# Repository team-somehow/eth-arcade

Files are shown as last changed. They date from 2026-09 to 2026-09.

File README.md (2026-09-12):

# ethonline-2026

TICK: a landscape **480×320** pygame crypto arcade for a Raspberry Pi handheld. **BOX RUN** is playable now: a box on the ETH price ladder and a 10-second clock that never stops — crank the dial to move the box, press A to buy the next 10 seconds. Prices are read-only. Money is paper by default; with `TICK_FUNDING=arc-testnet` it is real Arc testnet USDC: send it to the QR code on the device, play, and cash out back to the wallet it came from, through the [`TickEscrow`](contracts/) contract.

## Layout

| Path | What |
|---|---|
| [`firmware/`](firmware/) | Launcher + playable BOX RUN |
| [`design/`](design/) | Device renders, concept archive and actual game screenshots |
| [`substreams/`](substreams/) | The live ETH/USDC price: a Substreams module for Arbitrum and Base, the relay that serves it to the device, and `pools.py`, which finds pools in Messari's subgraphs |
| [`contracts/`](contracts/) | `TickEscrow`: USDC session escrow on Arc, with the owner as the house. Testnet: [`0x4FA3…8627`](https://testnet.arcscan.app/address/0x4FA3D366A08aD06D60A0aB141FFb9981EDeE8627) |
| [`ens/`](ens/) | Every player's wallet gets a `tick.eth` name on ENSv2 (Sepolia), with their stats as text records only the scorekeeper may write; the leaderboard is read back from ENS, on the device's LEADERS screen too |

## Where the prices come from

Every bet settles on the ETH/USDC price at the bell, so that price has to be live, updated every block, and hard to push. It comes from The Graph:

- **Substreams** (from The Graph Market) streams the swaps in every watched ETH/USDC pool on Arbitrum and Base, block by block: Uniswap v3 and v4 and Aerodrome Slipstream today, and any Sushiswap V3 pool `pools.py` adds. The module is built on Pinax's `uniswap_v3` and `uniswap_v4` packages, so it decodes no logs itself, and the same compiled module runs on both chains with only the pool list changed.
- **Messari's standardized subgraphs** say which pools to watch. They share one schema across protocols and chains, so `pools.py` asks Uniswap V3 and Sushiswap V3 the same question and gets back each pool's token order and decimals, which the module needs to turn a pool's state into dollars.
- **The device** combines the pools into one price, weighted by liquidity and leaving out any pool that strays from the rest, and prices the odds from how that price actually moves. More pools mean more trades, and more real moves to measure.

To play on it, run [`substreams/relay.py`](substreams/) and set `TICK_MARKET_SOURCE=substreams` in `firmware/.env`. The `sim` (default) and `coinbase` feeds are for playing without a relay.

## Quick start

```bash
cd firmware
python3 -m venv .venv
source .venv/bin/activate
pip install -r requirements.txt
python main.py
```

See [`firmware/README.md`](firmware/README.md) for controls and Pi/KMSDRM notes.

**On the device:** the dial moves your box up and down the price ladder; a short click buys the next 10 seconds (+10 USDC in paper play), pressing again adds more to the same box. Distance from spot sets the payout, priced from measured live volatility. On desktop, hold Up/Down to emulate a spun dial and press Escape to quit. See the [actual gameplay sheet](design/box-run-live/gameplay-sheet.png).

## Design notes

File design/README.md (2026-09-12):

# TICK design archive

## Current direction

White FDM case, charcoal painted bezel, existing red/yellow buttons, short side crank, tape assembly, Pi Zero 2 W, 3.5-inch landscape display. Enclosure size and crank attachment are NOT verified; measurements are required before CAD. Older screw-fastened and multi-color renders below are preserved as explorations, not the current build plan.

## Proposals in progress

- [INSERT COIN: the money and leaderboard flow](insert-coin/) — arcade-style deposit and payout, and a leaderboard that climbs your row one place at a time. 480x320 mockups, two animated moves, and the flow in plain words; not built yet. [Contact sheet](insert-coin/contact-sheet.png).

## Saved images and concepts

- [Latest crank / open-back appearance study](practical-crank/assembly.png)
- [Tape-assembled knob exploration](tick-tape-build.png) and [assembly notes](TAPE-BUILD.md)
- [BOX RUN six-step storyboard](box-run-storyboard/round.png) (archived concept)
- [BOX RUN hit/miss explanation](box-run-storyboard/outcomes.png) (archived concept)
- [Original device board](tick-device-concept.png)
- [Cream Cartridge exploration](render-round-2/01-cream-cartridge.png)
- [Graphite Terminal exploration](render-round-2/02-graphite-terminal.png)
- [Four game concepts](render-round-2/04-game-concepts.png)
- [Screen composition study](screen-studies.svg)
- [Initial long-form proposal](DEVICE-CONCEPT.md) and [two-day scope](TWO-DAY-PRODUCT.md)

All completed generated images available from the conversation are now copied into this repository. Some image generation requests were interrupted before returning an output (including the separate in-hand crank view and Orange Sandwich board); there are no completed files for those. Existing prompt files record prompts where available; the interrupted multi-image batches did not retain their prompt store. The render-round-2 README describes those proposed variants even when no image finished.

## Actual software screenshots

[BOX RUN gameplay contact sheet](box-run-live/gameplay-sheet.png) and individual screens in `box-run-live/` are rendered by the implemented pygame game, not imagegen. Recreate with `cd firmware && SDL_VIDEODRIVER=dummy SDL_AUDIODRIVER=dummy .venv/bin/python capture_box.py`.

The implemented game is BOX RUN: a box on the ETH price ladder with a 20-second window clock that never stops, priced from measured live volatility and staked in demo USDC. Two archives sit beside it — `box-run-build/` is the original aim/size/confirm version, whose sizing and confirmation steps were dropped, and `rush-build/` is a crank-a-flywheel detour (still runnable with `TICK_GAME=rush`). See [firmware instructions](../firmware/README.md) for running and controls.

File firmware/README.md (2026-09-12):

# ETH ARCADE / BOX RUN

Native pygame game for a **480×320 landscape** handheld. Runs on desktop for development and on the Pi's configured SDL display.

**BOX RUN** is a box on the ETH price ladder and a clock that never stops. A 10-second window is always running; **cranking the dial moves your box** up and down, and **A buys the next 10 seconds** at wherever the box is sitting. At the bell, the window settles against the live price — inside the box and you're paid, outside and the stake is gone — and the next window starts in the same frame. There is no size step, no confirmation, and no early exit.

The box is **always the same size** — $1.41 on $2,500 ETH — so there is nothing to learn about it and nothing that changes under you. How far you park it from spot is the only decision, and only the *payout* reacts to the market.

## Controls

The rotary encoder is the game: GPIO21 CLK, GPIO20 DT, GPIO16 switch, 3.3 V logic. Two panel buttons sit beside it, each shorting its pin to ground against the internal pull-up — nothing else in hardware:

| Button | BCM | Header pin | Does |
|---|---|---|---|
| Red | GPIO13 | 33 | Back / home (same as a long encoder click) |
| Yellow | GPIO26 | 37 | Buy / confirm (same as an encoder click) |

Ground for both is any GND pin; 34 and 39 are the nearest. **BCM numbering, not header position** — GPIO13 is pin 33, GPIO26 is pin 37, which is where this usually goes wrong. Presses are edge-triggered, so holding a button repeats nothing, and a button held while the game starts is ignored rather than firing on the first frame. If the pins are missing or already claimed, the pad simply does not open and the encoder carries on alone.

| Input | Action |
|---|---|
| Turn the dial | Move the box up/down the price ladder — until a bet is placed |
| Short click | Buy the next 10 seconds: +10 USDC on the box where the cursor is |
| Long click (0.65 s) | Back to the launcher |

Press A again in the same window and the extra 10 goes onto **the same box** — the first press fixes that window's level. After that the dial is **locked out entirely**: the box does not move, does not shrink, and no second cursor appears. Only money can still be added, and only by pressing A. The dial frees up again when the bell rolls the window over.

Placing a bet turns the dashed box **solid where it stands**, with a pop. That is the signal that the dial is no longer yours: turn it anyway and the box shakes and the status line says `LOCKED / YELLOW ADDS 10`.

Spending money on a dial nudge would be worse than a dead dial, which is why adding stake stays on the button.

Desktop and touch equivalents: Up/Down (or W/S) held down emulates a spun dial, Right/Enter/Space is the short click, Left/Z/Backspace the long one, `F` opens the loader, and **Escape quits the program immediately** from any screen. On a desktop the game opens in a plain 480×320 window; only the Pi gets the fullscreen panel. Tapping above the aim box raises it and tapping below lowers it (`design/box-run-live/touch-zones.png`); buying stays on the button.

`TICK_GAME=rush` still selects the earlier crank-a-flywheel game; `box` is the default.

The launcher is an attract screen in the same night city: the rider runs a scripted demo loop — a hit, a backflip, a hat trick, then a greedy miss that puts the fire out — under a bobbing logo, with the live ETH price in the corner. The demo line is made up; the ticker and the balance are real. PLAY and LOAD USDC sit on the street; the dial toggles between them, and tapping anywhere in the scene plays.

## Reading the screen

Time is one horizontal scale across the whole screen, 16 px a second. A rider on a one-wheeler sits a quarter of the way in at *now*, the wheel resting on the live price; history trails off to the left, and every bell is a dotted post ahead that slides toward the wheel. A box is drawn centred on the post of the bell it settles at, so it arrives under the wheel at the exact moment it is judged: be inside it as you pass through and you're paid. There are no columns.

| On screen | Meaning |
|---|---|
| `+0.62` beside the price | How far the price has come since this window opened |
| Dashed grey line, `OPEN` | The price this window opened at — the chart is anchored here |
| `07s` over a post | Time to this window's bell |
| Dotted line ahead of the wheel | Where the price is now, carried forward to read against the boxes |
| Solid yellow box | Your live bet, arriving at this bell; it glows while the price is inside |
| Solid cream box | Bought and locked for the next bell |
| Dashed yellow box | The cursor, with its live quote; a fresh one slides in from the right after every bell |
| Green / red box behind the rider | A box that already settled, with a dot where the price landed |
| `20 @ 2.0x` | Stake on that box and the multiple it pays |
| Small triangle | The box sits past the top or bottom of the visible band |

The wheel is a single wheel on purpose: the price line is jagged, and legs or a two-wheeled base would visibly clip into it, while one wheel touches it at exactly one point. The rider leans into the slope and reacts to results — a hop on a hit, a backflip on 5x or better, a wobble on a miss. **Three hits in a row is a hat trick**: the rider leans back into a one-wheel wheelie with a jetpack on fire, and stays lit until a miss puts it out.

The scene — sky, two parallax rows of city, the street, the rider — is drawn in code (`games/box_scene.py`), like the sound, with no image assets. Everything moves on the clock rather than on ticks, and the wheel, the camera and the cursor ease toward where the model says they are, so a price tick or a detent is a glide rather than a jump.

The visible band is exactly **two box-heights either way** (±$2.83 on $2,500 ETH), which is what makes a dollar of drift a visible swing rather than a wobble. Widening it to fit every reachable box would flatten the price back out, so a box cranked to the far edge is clamped with a triangle instead.

**The chart is anchored on the window's opening price, not on spot.** Anchoring on spot re-centres the view every tick and pins the newest point to the middle of the screen, which makes movement impossible to see — the price appears still while the world slides around it. Against a reference that holds still for the whole window, a move reads immediately, and the `MOVE` figure puts a number on it.

## Odds

Distance is the whole risk decision, so the payout is priced from what the market is actually doing rather than a fixed table. Park the box on spot for roughly 2x; crank it to the edge of its reach for 10x or more, capped at 25x.

Geometry is fixed in basis points of the window's opening price — a $1.41 box, 18c crank steps and $2.12 of reach on $2,500 ETH — so **volatility moves the odds and never the box**.

Those numbers are quoted for a 20-second window and **scaled by the square root of time**, because that is how far a price travels. `WINDOW_S` is therefore a safe knob: halving it without shrinking the box would leave a box on spot a near-certainty paying 1.2x and everything else pinned to the cap — a flatter game, not a faster one. Scaled, ten-second windows keep the ladder the twenty-second build had: about 1.5x on spot at the bell, 25x at full reach, 2.0x to 9.7x for the same boxes bought a window early. Sizing the box in sigma instead (as this first did) means a bet already placed gets redrawn at a different size when the market picks up, which is both confusing and dishonest about what you bought. The cost of fixing it is that a violent market makes the same box genuinely hard to hit; the multiple rises to match, which is the honest response rather than quietly making the target bigger.

The estimator is **realized variance over the last minute of wall time**: squared returns summed and divided by the time they span, with time spent sitting on one price counted as exactly that. A pool nobody swaps in, or a ticker with no new trade, is a calm market — and the bell settles on that same price, so pricing it as a typical one sells a near-certain box at 2x. The first version skipped repeated prices and fell back to "typical ETH" whenever it saw too few moves, which is precisely what a flat Coinbase or Substreams stretch produces: parking the box on the line won 58 bets out of 58. A flash spike or feed glitch is kept from inflating the odds by capping each move at four times the median move. And every estimate is made as if the window began with ten seconds of ordinary ETH, so the first seconds of data, or a market just waking from a lull, are not priced as if nothing could move; a minute of real data outweighs that six to one. The estimate is cached per tick, so the renderer can ask for it freely.

**A quiet market sells nothing.** If the price has not changed for 15 seconds, A refuses with `MARKET QUIET / NO BETS` and the aim box reads `QUIET`: on a line that never moves, a box on spot is a certain win at any multiple over 1x. Nothing that quotes under 1.05x is sold either: a near-certain box is not a bet worth selling. At start-up nothing is sold until the feed has been read — it has moved, with three seconds or ten moves behind it, since a feed that has not moved yet cannot be told from a dead one — and the screen says `READING THE MARKET...`; prices are read from boot, behind the launcher, so this is normally over before you press play. Bets already down ride to their bell as normal.

Two details that matter for fairness. Each press is priced at **that press's** odds, so topping up a box after the price walks toward it costs what it's worth then, not what it was worth when the level was fixed. And the horizon runs to the bell being bought, so buying 15 seconds early prices 35 seconds of drift — a different bet, not a free one.

## Sound

Everything is synthesized at startup — square waves, no audio assets, no dependencies — and it builds in about 0.16s.

### Music

Three looping beds, and the game picks one every frame from what is actually at stake:

| Bed | When | What it is |
|---|---|---|
| `idle` | Launcher, or nothing staked | Sparse A-minor bass and a slow arpeggio |
| `live` | Money on the next or current window | Driving bass, fast arpeggio, offbeat hats |
| `final` | Last three seconds of a live bet | Same bass, a tense descending lead, hats on every step |

Each bed is layers of **monophonic** 2-second loops, one per reserved mixer channel, so the mixer does the polyphony and Python never mixes a sample — which matters, because `audioop` was removed in 3.13. Loops are assembled from a cached palette of note renders rather than computed per sample per bar, which is the difference between 0.16s and several seconds of work at boot on a Pi. Every layer in every mode is exactly the same length, so switching bed restarts the bar cleanly instead of drifting the parts apart.

### Cues

A clip is a list of (start_hz, end_hz, seconds) segments, with phase carried across segments so a clip can glide in pitch instead of only beeping. Every cue answers a question you would otherwise have to read off the screen:

| Cue | When |
|---|---|
| Rising detent clicks | Every crank step, pitched by how far out the box has moved — the risky end of the reach sounds higher |
| `buy1` → `buy2` → `buy3` | Stacked presses on the same box, each a note higher |
| Upward swoop | The price just crossed **into** your live box |
| Downward swoop | It just crossed **out** |
| Ticks in the last 3s | Pitched high if the money is currently winning, low if it is not, and doubling in rate inside the final two seconds |
| Two-tone bell | A window rolled with no money down — the game's heartbeat. A result speaks instead of the bell |
| Fanfare | A win, longer and higher above 5x |
| Falling thud | A miss, or a flat neutral one for a voided window |
| Longer, higher fanfare | A jackpot at 15x or more |
| Tiny high click | The box passing over spot as you crank through it |
| Double low buzz | Cranking a box that is already locked |
| Falling sweep | The price feed went stale |
| Blip / rising chime / falling chime | Menu move, entering the game, backing out |
| Two-note chime | USDC loaded |

The two that matter most are the box-crossing swoops and the pitched countdown: together they tell you whether you are winning without looking, which is the whole point of a handheld you play with your thumb.

Levels are sized so three overlapping cues plus a bed peak at about 21k of 32767 — nothing clips, and the music sits at roughly half the level of the cues.

**Audio output on the Pi.** A Pi 5 has no analog jack, so ALSA alone offers only the two HDMI outputs and opening one fails with nothing connected. Sound works through the **pipewire-pulse** server instead — on this device that reaches a paired Bluetooth speaker. Do not force `SDL_AUDIODRIVER=alsa`: it bypasses the sound server and finds only the dead HDMI sinks. If the mixer cannot open at all, the game runs silently by design (`Sounds` catches it and every `play` and `music` becomes a no-op, which is tested).

Bluetooth adds 100-200ms of latency, so crank clicks trail the dial. A USB audio dongle is tighter; an I2S DAC such as a MAX98357A is tightest, but **it wants GPIO18/19/21 and GPIO21 is currently the encoder's CLK pin**, so the encoder would have to move first.

## Settlement

Only the price **at the bell** counts; sailing through the box mid-window pays nothing, and the boundary counts as inside. A quote from before the bell cannot settle a window however fresh it looks, so the display holds on `SETTLING` until a price stamped after the bell arrives. If none arrives within 4 seconds, the window is **voided and the stake refunded** — settling a real bet against the wrong moment's price is worse than not settling it. A stale feed also blocks new bets.

## Money

Balances are integer **micro-USDC** (6 decimals, the real USDC unit) so a session cannot accumulate float drift; payouts truncate downward rather than rounding money into existence. `wallet.py` holds the funding seam:

| `TICK_FUNDING` | Backend | Behavior |
|---|---|---|
| `demo` (default) | `DemoFunding` | Starts at 100 and mints local play money on +10/+25/+100 |
| `arc-testnet` | `arc.ArcFunding` | Real Arc testnet USDC through the [`TickEscrow`](../contracts/) contract. BOX RUN only |

`TICK_STAKE_USDC` sets the stake per press of A in BOX RUN and per ride in RUSH: 10 by default, as little as 0.000001. It is parsed as an exact decimal, and labels and balances show as many decimals as the stake has, so a 0.001 stake reads `0.001`, never `0.00`.

**Real USDC.** With `TICK_FUNDING=arc-testnet` the money button on the launcher reads INSERT COIN and opens `screens/money.py`, which shows the device's own Arc address as a QR code. Scan it in MetaMask and send any amount of USDC on Arc testnet. The device watches Arc for transfers to itself, keeps 0.01 of each for gas (USDC is Arc's gas token; set it with `TICK_GAS_FEE_USDC`), and locks the rest in `TickEscrow` with `openFor`, in the sender's name. That takes about 8 seconds. The launcher then shows `+0.49 USDC FROM 0x7ee8..CCac` and its money button turns into CASH OUT.

Bets run on the device exactly as in demo play. CASH OUT refunds a box bought for the next window, lets the live one land, then closes the session with the final balance, and the escrow pays it straight back to the address the USDC came from. The escrow pays out at most 5x a deposit, so a press that could win past that is refused with `MAX WIN REACHED / CASH OUT`. A deposit the house cannot cover, or one over the 2.5 USDC maximum, is sent back.

**The money screen** is one screen with four faces, and only one of them is up at a time — designed in [`design/insert-coin`](../design/insert-coin/). Which face is drawn comes from funding state that already exists on `ArcFunding`, plus two timers:

| face | when | ● B | ◆ A |
|---|---|---|---|
| INSERT COIN | no session open | home | — |
| COIN DROP | a deposit just landed | home | **PLAY NOW**, straight into the game |
| CASH OUT? | money down, money button pressed | not yet | **YES**, after a 0.5s beat |
| CASHING OUT | the payout is in flight | — | — |
| the ticket | the payout landed | home | see your rank |

The coin drop falls back to the launcher with PLAY focused if nobody presses anything for three seconds, and the ticket hands itself to the leaderboard after 2.5. CASHING OUT has no buttons, because pressing one cannot make Arc faster — but if the payout is still going after eight seconds (`PAYING_HOLD_S`) the red button becomes `< LEAVE IT RUNNING`, since the worker finishes the transaction whatever is on the panel and the launcher says so when it lands. The cash-out question exists because that press is the only irreversible, screen-less action on the device: the A that opens the card is ignored, so it takes a second, deliberate press to send the money. The ticket reports the run — in, out, P&L, boxes, hits, best win and the tx — from a `Ticket` snapshotted in `BoxGame.sync_funding` the moment the cash-out lands, because everything on it is about to be reset. Paper money keeps its own `+10 / +25 / +100` chooser inside `BoxGame`; none of this applies to it.

**The leaderboard moves.** `screens/board.py` reads every `tick.eth` player from ENS, best P&L first, and the wallet on this device is picked out — in the list, or pinned under it with its real rank. Arriving from a payout it does something more: `BoardScreen.arrive()` is handed who just cashed out and what their run was worth, and from then until the scorekeeper catches up the board **holds the picture it already had**, ghosts the pending P&L beside your old row, and says `SCORING YOUR RUN ON ENS`. `BoardFeed` parks a good read in `pending` instead of swapping it in, and polls every 3s rather than 20 while it is waiting — the scorekeeper writes a few seconds after the escrow closes, so this is usually one or two reads. A run counts as scored when the name's `tick.sessions` goes up, the only signal ENS gives us.

Then the board is *seen* to change rather than found already changed. `Move` is the whole animation: 0.7s holding, one adjacent swap every 0.52s, 1.7s to settle. Your plate lifts over the list, the row above slides under it, both numbers roll at the same instant so they never read as the same rank, `UP 1` becomes `UP 2` becomes `UP 3`, and your P&L counts up the whole way — to cents while it runs, exact when it rests. Land in the top three and confetti comes off the plate under `ON THE PODIUM!`; a bad run runs the same movement downward with no celebration at all, just `THAT ONE COST YOU. GO AGAIN?`. Two cases have no row to trade places with, so the number itself counts instead: a player pinned below the visible six, and a first ever run, whose row drops in from the top and stamps `NEW ENTRY`. If ENS has not been written after 45 seconds (`SCORE_WAIT_S`) the board says so and goes back to being a board. Afterwards the yellow button reads `PLAY AGAIN` and goes to INSERT COIN, which closes the loop.

The device key is created on first run in `firmware/.tick/device.json`, and the open sessions, balance and last block read are saved in `.tick/arc-testnet.json`; the folder is gitignored. A restart resumes play and finishes an interrupted cash-out. Chain work runs on its own thread, so a slow RPC never stalls a frame. Real funds need `eth-account` and `qrcode` from `requirements.txt`; demo play does not. The odds still carry no house edge.

## Prices

| `TICK_MARKET_SOURCE` | Feed |
|---|---|
| `sim` (default) | Seeded 20 Hz Gaussian walk at roughly live ETH volatility — about 0.03% over ten seconds. Tick spacing is counted in integer microseconds, so the same wall-clock time produces the same ticks at any frame rate |
| `coinbase` | Public Coinbase REST ticker at 5 Hz on a worker thread, read-only |
| `substreams` | ETH/stable pools on Arbitrum and Base (Uniswap v3 and v4, Aerodrome Slipstream), from The Graph's Substreams via `substreams/relay.py` on a laptop or server at `SUBSTREAMS_BASE_URL`. One tick per block, priced as the liquidity-weighted average of the pools, leaving out any pool more than 0.5% from the rest, and aged by block time |

`TICK_ASSET` picks the coin: `eth` (default), `btc`, `sol` or `hbar`, each priced in USD, and HBAR shown to five decimals. `sim` starts each coin at a typical price and walks it at that coin's rough live volatility, and `coinbase` polls its `-USD` product. `substreams` watches ETH pools only, so it refuses any other coin. Box geometry is in basis points of price, so the game plays the same on any of them.

The Substreams feed repeats the last price on blocks where nothing traded, because that is still each pool's price. Volatility therefore counts only moves, measured from the previous move, or those repeats would read as a calm market.

Settings like this one live in `firmware/.env` (copy `.env.example`), which `main.py` reads at startup. A value set in the shell overrides the file, so `TICK_MARKET_SOURCE=coinbase .venv/bin/python main.py` works for a one-off run.

A 20-second window needs a trace rather than a staircase, which is why the live adapter polls at 5 Hz (well inside the public rate limit) instead of once a second. Payloads are validated before use — finite positive price, timezone-aware timestamp, no future stamp — and carry a sequence number and source age, so out-of-order or stale ticks cannot price or settle anything. A production adapter should use the venue's WebSocket trade stream.

The feed is read-only. With demo money every bet is paper; with `arc-testnet` the bets still run on the device, and only deposits and cash-outs touch the chain.

## Run, test, capture

```sh
cd firmware
.venv/bin/python main.py                    # or: python3 -m venv .venv && .venv/bin/pip install -r requirements.txt
SDL_VIDEODRIVER=dummy SDL_AUDIODRIVER=dummy .venv/bin/python -m unittest discover -s tests -v
SDL_VIDEODRIVER=dummy SDL_AUDIODRIVER=dummy .venv/bin/python capture_box.py
```

On Raspberry Pi, install the distribution's `python3-pygame` and run `python3 main.py` with the panel configured; the display bootstrap may re-exec under system Python for KMSDRM support.

Captures go to `design/box-run-live/` at native 480×320, rendered by the real game rather than image generation. Tests cover the window clock rolling on its own, buying and topping up, the cursor never moving a bought box, box height tracking measured volatility, fair odds against the stated probability, the multiple cap, inside/boundary/outside settlement, pre-bell quotes being rejected, voiding after a feed gap, whole-micro payouts, and every screen rendering.

## Pi display note

`hardware.md` records a prior Pi 5 setup, including KMSDRM device index **2**. The actual Pi Zero 2 W may use another index. Set `SDL_VIDEO_KMSDRM_DEVICE_INDEX` for the connected panel when running without a desktop; do not assume the Pi 5 card index applies. Display overlays, refresh rate, encoder direction and physical fit still need on-device verification, as does whether the SPI panel sustains the target 30 FPS full-frame redraw.

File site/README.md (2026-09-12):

# ETHarcade.fun landing page

Run `npm install` and `npm run dev`. Build the deployable site with `npm run build`.

## SDK documentation on the same origin

The complete SDK docs site is served at `/docs/`, including its sidebar,
search index, examples, source pages, theme switch, and mobile navigation.
The landing page's Docs link and SDK resources point there.

`predev` and `prebuild` copy the committed `../sdk/web/dist/` site into
`public/docs/`, so the production output includes `dist/docs/`. Deploy the
entire `site/dist/` directory. Serve existing static files before any SPA
fallback so `/docs/*.html`, scripts, and styles remain accessible.

After changing SDK Markdown or Python source, run `npm run docs:generate`
(Python 3 required) and commit the regenerated `sdk/web/dist/` files. Normal
landing-page builds only need Node, using that committed documentation build.
The copied `public/docs/` directory is generated and ignored by Git.

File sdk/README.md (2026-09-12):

# TICK SDK

Build a crypto arcade game for the TICK handheld in one file.

The device is a 480×320 landscape screen, a rotary dial, two buttons and a
speaker. A game on it is always the same shape: **a claim about where a price
will be at a known moment, backed by money**. This SDK owns everything around
that claim — the live price, the clock, the odds, the wallet, the settlement,
the input and the noise — so your game only has to say what a bet *is*, what
wins, and what it looks like.

```python
from tick import Game, run
from tick.hud import clear, draw_clock, draw_hud
from tick.ui import YELLOW, say

class Coinflip(Game):
    title = 'COINFLIP'
    window_s = 10.0

    def setup(self, ctx):
        self.pick = 'UP'

    def on_action(self, ctx, action):
        if action.name in ('UP', 'DOWN'):
            self.pick = action.name
        elif action.name == 'A':
            anchor = ctx.open_price
            ctx.bet(anchor, 1e9) if self.pick == 'UP' else ctx.bet(0.0, anchor)

    def draw(self, ctx, screen):
        clear(screen)
        say(screen, self.pick, 240, 120, 32, YELLOW, center=True)
        draw_clock(ctx, screen)
        draw_hud(ctx, screen)

run(Coinflip())
```

That is a complete, playable game with live prices, fair odds computed from
measured volatility, a round clock that never stops, an integer-USDC wallet,
dial and button input, and a full set of arcade sound cues.

## Install

```bash
cd sdk
python3 -m venv .venv && source .venv/bin/activate
pip install -e .                 # demo play: only pygame
pip install -e ".[chain]"        # + real USDC settlement and ENS names
pip install -e ".[pi]"           # + the dial and the panel buttons
tick doctor                      # what is installed, and whether the feed answers
```

Python 3.11 or newer.

## Sixty seconds

```bash
tick new mygame          # scaffold a playable game
python mygame.py         # play it on simulated prices
tick prices --source coinbase --limit 10       # watch a live feed in the terminal
tick run mygame.py --source coinbase           # play it on real prices
```

## What you get

| Layer | Module | What it owns |
|---|---|---|
| Ticks | `tick.feeds` | one validated `PriceTick`; simulated, exchange, on-chain and recorded feeds |
| Market | `tick.market` | history, realized volatility, fresh / quiet / ready, probability of a range |
| Odds | `tick.pricing` | chance → fair multiple, with a cap, a floor and a house edge you set |
| Money | `tick.money` | integer micro-USDC wallet; nothing here is a float |
| Settlement | `tick.escrow` | deposits, sessions and payouts on-chain, on a worker thread |
| Identity | `tick.identity` | a readable name per wallet, and a leaderboard read from ENS |
| Rounds | `tick.rounds` | the clock that never stops, and refuses to settle on the wrong price |
| Bets | `tick.bets` | place, top up, settle, refund — the only code that moves money |
| Your game | `tick.game` | `Game` and `GameContext` |
| Loop | `tick.runtime` | `run()`: 30 FPS, input, cues, shutdown |
| Screen | `tick.hud`, `tick.ui` | price ladder, HUD, palette, synthesized sound |

## Documentation

All of it is also a **browsable site** with search, built from these same
Markdown files — open [`web/dist/index.html`](web/dist/index.html) straight
from disk, or:

```bash
tick docs                # build it and open a browser
python web/build.py      # build only, into web/dist/
```

* **[PLAN.md](PLAN.md)** — the system from first principles, with examples, and
  the increment-by-increment plan to build or extend it.
* [docs/writing-a-game.md](docs/writing-a-game.md) — the tutorial, start here.
* [docs/prices-substreams.md](docs/prices-substreams.md) — putting an on-chain
  price under your game: Substreams, the relay, and how many pools become one
  number you can settle on.
* [docs/money-arc.md](docs/money-arc.md) — real USDC: the escrow session model,
  why there is no transaction per bet, and how a player cashes out.
* [docs/identity-ens.md](docs/identity-ens.md) — giving every wallet a name and
  a public record with ENS, and reading a leaderboard back out of it.
* [docs/device.md](docs/device.md) — the screen, the dial, the buttons, the Pi.
* [docs/api.md](docs/api.md) — the whole public surface on one page.
* [web/README.md](web/README.md) — how the docs site is generated, and how to
  add a page to it.

## The command line

```
tick doctor                          what is installed, configured and reachable
tick new mygame                      scaffold a game
tick run mygame.py [--source ...]    play it
tick prices [--source coinbase]      print the feed
tick pools [-v]                      print every pool in the on-chain stream
tick record -o eth.ndjson --seconds 300      save a real market
tick replay eth.ndjson --speed 10            play it back
tick board                           the leaderboard, read from ENS
tick docs [--port 8000]              build the documentation site and open it
```

## Testing a game

Games that hold money need tests, and a game loop is testable only if it can
run without a window. `tick.testing.Harness` runs your real game class against
a real market on a clock you control:

```python
from tick.testing import Harness
from mygame import MyGame

def test_a_wide_bet_is_never_sold():
    h = Harness(MyGame(), seed=7).warm(25)
    assert h.ctx.bet(h.price * 0.5, h.price * 1.5) is None
    assert h.ctx.refused == 'TOO SURE TO SELL'
```

```bash
SDL_VIDEODRIVER=dummy SDL_AUDIODRIVER=dummy python -m unittest discover -s tests -t .
```

## Settings

Everything is configured by environment, read from a `.env` beside your game
(copy `.env.example`). Anything set in the shell wins, so a one-off run is
`TICK_MARKET_SOURCE=coinbase python mygame.py`.

| Setting | Values |
|---|---|
| `TICK_MARKET_SOURCE` | `sim` · `coinbase` · `substreams` · `replay` · `frozen` |
| `TICK_ASSET` | `eth` · `btc` · `sol` · `hbar` |
| `TICK_FUNDING` | `demo` · `arc-testnet` |
| `TICK_STAKE_USDC` | money per bet, e.g. `10` or `0.001` |
| `TICK_WINDOW_S` | round length, if the game does not fix it |
| `TICK_ROTATE` | `auto` · `0` · `90` · `180` · `270` |
| `TICK_SOUND` | `1` · `0` |

## Examples

| File | What it shows |
|---|---|
| [`examples/coinflip.py`](examples/coinflip.py) | the smallest real game: up or down at the bell |
| [`examples/ladder.py`](examples/ladder.py) | park a box on the price — the shape most games take |
| [`examples/ticker.py`](examples/ticker.py) | the data layer with no game and no pygame |
| [`examples/pools.py`](examples/pools.py) | every pool in the on-chain stream, block by block |

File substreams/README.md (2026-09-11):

# tick_eth_price

A Substreams module that reads Uniswap v3 and v4 swaps and outputs a per-block price for a chosen set of pools, on any EVM chain. Aerodrome's Slipstream pools emit the same swap event as Uniswap v3, so they work too. It is the ETH price source for BOX RUN, where each bet settles on the ETH price at the end of a ten-second window.

## Why several pools on two chains

A bet settles on one number, so that number has to move often, be hard to push, and reflect the market rather than one venue. One pool does none of that well.

- **It updates often.** Any one pool can go several seconds without a trade. Over one minute with all twelve pools, the combined price changed 41 times and never stood still for more than 2 seconds, one Base block.
- **It is hard to push.** A price taken from one pool can be moved by one large trade at the bell. Moving the median of many pools on two chains at the same moment costs far more.
- **It is a fairer price.** Pools disagree. At one moment on Base they were $3.47 apart, more than twice the height of a box in the game.
- **It gives the odds real moves to measure.** BOX RUN prices every box from the volatility it measures in the last minute of prices. A stretch where no watched pool trades reads as a calm market, and after 15 seconds of it the game stops selling. Every pool added is one more venue whose trades move the price.

The price is only a reference; bets never trade in these pools. They can settle in USDC on any chain, and the price is read where ETH has the deepest liquidity.

## How it works

```
sf.ethereum.type.v2.Block ──▶ Pinax uniswap_v3:map_events ──┐
sf.ethereum.type.v2.Block ──▶ Pinax uniswap_v4:map_events ──┤
sf.substreams.v1.Clock ─────────────────────────────────────┼──▶ map_pool_prices ──▶ tick.v1.BlockPrices
sf.ethereum.type.v2.Block ──────────────────────────────────┘
```

- **It builds on Pinax's `uniswap_v3` and `uniswap_v4` packages** instead of decoding logs itself. Those packages already turn every Uniswap log into typed events; this module keeps only the swaps for the pools it was given and converts each pool's `sqrtPriceX96` into a decimal-adjusted price. A v3 or Slipstream pool is named by its address. v4 keeps all its pools inside one contract, so a v4 pool is named by its 32-byte pool id.
- **It keeps no state between blocks**, so it starts at the chain head straight away, with nothing to backfill.
- **It emits a message for every block**, including blocks where nothing traded, so a consumer can tell a quiet market from a dead stream. The raw block is an input for this reason only: the engine skips a module whose inputs are all empty, and many Arbitrum blocks carry no Uniswap v3 event.
- **Every message carries its block time**, so a price is placed against the bell rather than against when it arrived. In testing, messages arrived about a second after each block.
- **The same compiled module runs on Arbitrum and Base.** Only the pool list changes.

The module reports each pool's price and in-range liquidity. Combining them is left to the consumer. BOX RUN averages them weighted by liquidity, after leaving out any pool more than 0.5% from the rest, so a trade in any pool moves the price by that pool's share.

## Where the pool list comes from

Every pool needs its token order and decimals, or its `sqrtPriceX96` turns into the wrong number. Messari's standardized DEX subgraphs on The Graph hold both for every pool, in one schema that is the same for every protocol and every chain. `pools.py` relies on that: it sends one query, unchanged, to every subgraph listed in `.env`, and adds the ETH/USDC pools it finds to the pool list.

```graphql
{
  protocols(first: 1) { name network }
  p0: liquidityPools(first: 20, where: { inputTokens: ["<WETH>", "<USDC>"] }) {
    id
    name
    inputTokens { id symbol decimals }
    inputTokenBalances
    fees { feeType feePercentage }
  }
}
```

The subgraphs are Uniswap V3 on Arbitrum and Base, and Sushiswap V3 on Arbitrum. Sushiswap V3 pools emit the same swap event as Uniswap v3, so Pinax's `uniswap_v3` package decodes them and this module prices them with no change. A new protocol costs one subgraph id in `.env`, and nothing else.

```sh
python3 pools.py             # add what it finds to .env
python3 pools.py --dry-run   # show it and change nothing
```

It keeps pools with a trading fee of 0.05% or less that hold at least 25,000 USDC. Pools with higher fees are left out: nobody corrects their price until it is a fee off, about $7 at 0.3%, which is more than a box. Size is read from the USDC the pool holds rather than from the subgraphs' USD figures, which put some of the biggest pools at $0.

It only ever adds. A pool already listed stays exactly as written, and a chain whose subgraphs cannot be reached keeps its list, so a bad run never costs the ETH/USDC price a pool. Restart `relay.py` afterwards to stream the new pools. It needs `GRAPH_API_KEY` in `.env`, an API key from [Subgraph Studio](https://thegraph.com/studio).

The Slipstream and v4 pools have no Messari subgraph, so they are listed by hand: picked by trading volume, with their token order and decimals read from the pool contracts.

Each output price includes the hash of the transaction behind it, so a settled window can be checked afterwards against the swap the subgraph recorded for that pool.

## Output

One `BlockPrices` per block, listing only the pools that traded in it:

```json
{
  "blockNumber": "503790132",
  "timestampMs": "1789063794000",
  "prices": [{
    "pool": "0xc31e54c7a869b9fcbecc14363cf510d1c41fa443",
    "price": 2456.759457684401,
    "sqrtPriceX96": "3927000007035700886487060",
    "liquidity": "26649090794393043",
    "swaps": 1,
    "ordinal": "5773",
    "txHash": "0x39ed645a77cad585294f380650d60576137a6892c0598dcecfd5b0fcda04bc3c"
  }]
}
```

## Run

Get a key from [The Graph Market](https://thegraph.market) with `substreams auth`, or set `SUBSTREAMS_API_KEY`. Then:

```sh
cargo build --target wasm32-unknown-unknown --release

# Arbitrum, with the default pool list
substreams run ./substreams.yaml map_pool_prices -e arb-one.streamingfast.io:443 -s -1 -o jsonl

# Base: same module, different pools
substreams run ./substreams.yaml map_pool_prices -e base-mainnet.streamingfast.io:443 -s -1 -o jsonl \
  -p map_pool_prices=0xd0b53d9277642d899df5c87a3966a349a798f224:18:6
```

Pools are passed as `0xpool:decimals0:decimals1`, comma-separated, where `0xpool` is a pool address or a v4 pool id. Add `:invert` to quote token0 per token1 instead of token1 per token0.

## Choosing chains

`stream.sh` reads `.env` (copy it from `.env.example`) and starts one stream for each chain in `TICK_CHAINS`. It merges them into a single JSON-lines stream and adds a `chain` field to every line.

```sh
TICK_CHAINS=base            # one chain
TICK_CHAINS=arbitrum,base   # both
```

To add a chain, set its endpoint and pools as `TICK_ENDPOINT_<CHAIN>` and `TICK_POOLS_<CHAIN>`. For `pools.py` to find its pools too, add its subgraphs, WETH and USDC as `TICK_SUBGRAPHS_<CHAIN>`, `TICK_ETH_<CHAIN>` and `TICK_USDC_<CHAIN>`.

## Serving it to the device

The handheld does not run Substreams itself. `relay.py` runs `stream.sh` on a laptop or server and serves the same lines over HTTP. It needs the built module, `.env` and a Substreams key, as above.

```sh
cd substreams
python3 relay.py                  # serves http://<this machine>:8787/stream
python3 relay.py --port 9000      # another port

# check it from another terminal: one JSON line per block
curl -N http://localhost:8787/stream
```

Stop it with Ctrl+C; that stops the streams too.

The device keeps one connection open to `/stream` and gets each block as soon as it arrives, so the relay adds only the local network's delay. A device that connects is first sent the latest price of every pool that has traded since the relay started, so it does not have to wait for each pool's next trade. The Substreams key stays on the relay's machine.

On the device, set `TICK_MARKET_SOURCE=substreams` and `SUBSTREAMS_BASE_URL=http://<relay address>:8787` in `firmware/.env`.

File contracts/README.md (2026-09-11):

# contracts — TickEscrow on Arc

`TickEscrow` is a USDC escrow for TICK play sessions, with the owner as the house. Bets run off-chain on the device; the chain holds both sides' money and settles each session in one transaction.

- **The house** is the owner's USDC, funded with `fund` (a small bankroll, $10–20 on mainnet). A player's loss stays with the house; a win is paid from it.
- **A session** is one player's USDC locked for one device. When play ends, the player is paid the device's final balance.
- **A device can open for its player.** `openFor(player, amount, device)` locks the caller's USDC in `player`'s name, and every payout or refund goes to `player`, never to the caller. This is how the device puts USDC a player sent it into escrow.
- **Opening a session reserves** `deposit × winCapBps` of house money (4x by default), so a win is always payable. Concurrent sessions each reserve their own share, and a session that does not fit reverts. A close above deposit + reserve is capped.
- **The house is locked while any session is open.** `withdraw` reverts until every session has closed, and even then it can only take house money, never a player's deposit. To drain the house, `setPaused(true)` stops new sessions; open ones still close.
- **The device closes** either by sending `close` itself, or by signing an EIP-712 `Close(sessionId, finalBalance)` that anyone submits with `closeWithSig` — so the device never needs gas. The owner cannot close a session.
- **If a device never closes**, the player can `reclaim` the deposit after `sessionTimeout` (1 day). The deadline is fixed when the session opens, so the owner cannot push it back.

```
player ── open(amount, device) ──────────────▶ TickEscrow ◀── fund / withdraw (no open sessions) ── owner
device ── signs Close(id, final) ─▶ anyone ── closeWithSig ─▶ TickEscrow ── payout ─▶ player
```

## Setup

```sh
curl -L https://foundry.paradigm.xyz | bash && foundryup
forge install foundry-rs/forge-std OpenZeppelin/openzeppelin-contracts@v5.4.0 --no-git
cp .env.example .env   # then set ARC_DEPLOYER_KEY
```

## Test

```sh
forge test
```

Unit tests run against a 6-decimal mock USDC: opening reserves house money and concurrent sessions cannot over-reserve it, pausing stops new sessions but not closes, losses go to the house, wins are paid from it and capped, the house cannot withdraw during a session or more than it holds, only the owner can fund, withdraw, pause or set limits, signatures bind the balance and cannot be replayed, reclaim waits for a timeout the owner cannot extend, and a fuzz test checks the contract always holds what it owes and no money is created or lost.

Several players at once: two players with their own devices settle independently (one wins, one loses, each paid exactly), one device cannot close another player's session or reuse a signature across sessions, a player cannot reclaim someone else's deposit, and one stuck session keeps the house locked until it is reclaimed.

[`TickEscrowInvariant.t.sol`](test/TickEscrowInvariant.t.sol) goes further: three players and the house make random opens, closes (direct and signed, including above the cap), reclaims, withdrawals, top-ups and drains (pause, end every session, withdraw, unpause) in random order, and after every call the contract must be solvent, its totals must match the open sessions, every payout must be exact, no USDC may be created or lost, the house must never have withdrawn while a session was open, and it must always have been able to withdraw once none were. Each run must also have had two players' sessions open at once and used every way out, so a run that skipped everything cannot pass.

## Deploy to Arc testnet

```sh
forge script script/Deploy.s.sol --rpc-url arc_testnet --broadcast
./smoke.sh <TickEscrow address>
```

`smoke.sh` runs one real session against Arc's USDC: it funds the house if needed (`SEED_USDC`), opens a session (`SESSION_USDC`) for a throwaway device key, has that key sign a final balance 50% up, and settles it with `closeWithSig`. While the session is open it simulates the owner withdrawing and expects `SessionsOpen`; after the close it expects the same withdraw to succeed. Each run writes a report to [`results/`](results/) with every transaction's status, gas and explorer link, the house's state afterwards, and a PASS/FAIL check that the player's balance moved by exactly the seed, deposit, payout and gas.

| Network | TickEscrow | Deploy tx |
|---|---|---|
| Arc testnet (5042002) | [`0x4FA3D366A08aD06D60A0aB141FFb9981EDeE8627`](https://testnet.arcscan.app/address/0x4FA3D366A08aD06D60A0aB141FFb9981EDeE8627) — source verified | [`0x2e59…3047`](https://testnet.arcscan.app/tx/0x2e59a2a3cf398edba3441cbc08ede7dd8980cd253c7c2f3d3c63a81293543047) |
| Arc mainnet | not deployed yet | |

Owner (the house) on testnet: [`0x7ee85B080701330bf53Be62B7E72fcDD034eCCac`](https://testnet.arcscan.app/address/0x7ee85B080701330bf53Be62B7E72fcDD034eCCac). After deploying, the owner funded the house with 10 USDC ([tx](https://testnet.arcscan.app/tx/0x49772362e0598d814a0d67561eccc3137ad328cbdf00e6cd638b1854a23bb646)) and set a 2.5 USDC maximum deposit, keeping the 4x win cap and 1-day timeout ([tx](https://testnet.arcscan.app/tx/0xe02d69013a1f51b7132557d2255b409f97c998d3a656cae1ff28b48fed72f870)), so four full-size sessions fit at once.

Earlier testnet deploys are retired and empty: [`0xC50d…1b3B`](https://testnet.arcscan.app/address/0xC50dC94A6b9AB85A5B541Da9DB5df83870A41b3B), the same contract without `openFor` (house withdrawn in [this tx](https://testnet.arcscan.app/tx/0xa68c72369dbf87ceb36bb185817131d409e8125dd97dd6b94e9e1f84117797f8)), and two ERC-4626 vaults where outside LPs would have funded the house for share tokens, [`0xbddd…1daC`](https://testnet.arcscan.app/address/0xbddd8233a65b6f329245dEaFc917543EF48e1daC) (`sHOUSE`) and [`0xb268…016c`](https://testnet.arcscan.app/address/0xb268Df5120649A296A2EBe5fb0F367f68c7C016c) (`tvUSDC`). With only the team funding the house, the share token had no job, so it was dropped.

### Device flow on testnet

What the game does with real funds (`TICK_FUNDING=arc-testnet` in [`firmware/`](../firmware/)), run end to end against this deploy ([report](results/arc-testnet-device-flow-20260911.md)):

| Step | What happened | Tx |
|---|---|---|
| Deposit | The player sends the device 0.05 USDC as a plain native send, as MetaMask's send screen does | [`0xfff4…79f9`](https://testnet.arcscan.app/tx/0xfff4ea8c3a983b718b0606f54061acb1ec1ca71bfa5926a1a58583d668d779f9) |
| Open | 8.4 s later the device has approved the escrow once and called `openFor`: session 1, 0.04 locked in the player's name after a 0.01 gas fee, 0.16 of house money reserved | [`0x24f3…c0ec`](https://testnet.arcscan.app/tx/0x24f3990c01acc45b0e23462b346b0c249d090bd77f5c6c47ddb82102d92cc0ec) |
| Close | The device closes at 0.045 (a 0.005 win) and the escrow pays it straight to the player | [`0x97c9…bfaf`](https://testnet.arcscan.app/tx/0x97c982d75198b90af0f29a7cc1e05a49e7283e06c28c851d5e8724078f04bfaf) |

The player's balance moved by exactly −0.05 + 0.045 − 0.0005 gas. The device kept the 0.01 fee and paid its own gas (0.007) out of it.

### First smoke session, on the previous deploy (`smoke.sh`)

One full session against Arc's real USDC ([report](results/arc-testnet-20260911T150436Z.md)). The device key ([`0x1EBa…5DA8`](https://testnet.arcscan.app/address/0x1EBaba2e05D833C654c0cb8595A2F09D18445DA8)) never held funds or sent a transaction; it only signed the close.

| Step | What happened | Tx |
|---|---|---|
| Approve | Player lets the contract pull USDC | [`0x70fa…0555`](https://testnet.arcscan.app/tx/0x70fa1cfc1105c177ba9d11c7ac6aac44bb02c44fa914d8f6249e9116129a0555) |
| Fund | Owner funds the house with 0.1 USDC | [`0xaa78…402e`](https://testnet.arcscan.app/tx/0xaa78326e715ecb60a44fef795f1883205d9d2c73d50ea2eaeb25ba4509c0402e) |
| Open | Session 1: 0.01 USDC locked, 0.04 of house money reserved; an owner withdraw now reverts with `SessionsOpen` | [`0xc41a…f850`](https://testnet.arcscan.app/tx/0xc41a184aeef8216d882a8e705bc0789eb5e0aef1efde77d8db255677434df850) |
| Close | Device signs a final balance of 0.015; the player submits it; 0.005 win paid from the house; an owner withdraw now succeeds | [`0x0ec3…13bd`](https://testnet.arcscan.app/tx/0x0ec3721c841ac54381864ea9d2b64c41c6001a38c9754a2cec6025fb802213bd) |

Afterwards the house held 0.095 USDC (0.1 seed − 0.005 win) with nothing reserved, and the four transactions cost 0.0085 USDC of gas together.

## Arc notes

- USDC's ERC-20 interface is at `0x3600000000000000000000000000000000000000` with **6 decimals**. It is the same balance as the 18-decimal native gas token; every amount in this contract uses the 6-decimal view.
- **Foundry cannot simulate Arc's USDC locally.** Each transfer calls an Arc-only precompile (`0x1800…0001`, `isBlocklisted`) that Foundry's EVM lacks, so fork tests and scripts that move USDC fail before broadcast. Unit tests use a mock, the deploy script makes no USDC calls, and `smoke.sh` checks the real token on-chain with `cast`.
- Transactions need `maxFeePerGas` of at least 20 gwei; the RPC's own estimate is above that.

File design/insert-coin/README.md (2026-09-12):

# INSERT COIN — the money and leaderboard flow

Arcade rules: you put a coin in, the machine gives you credit, you play, and
when you walk away the machine pays you and moves your name on the board.

Mockups drawn at the real 480x320, using the game's own palette, fonts and
night-city background. Proposals, not running firmware. Regenerate with:

```
cd design/insert-coin && ../../firmware/.venv/bin/python make_mockups.py
```

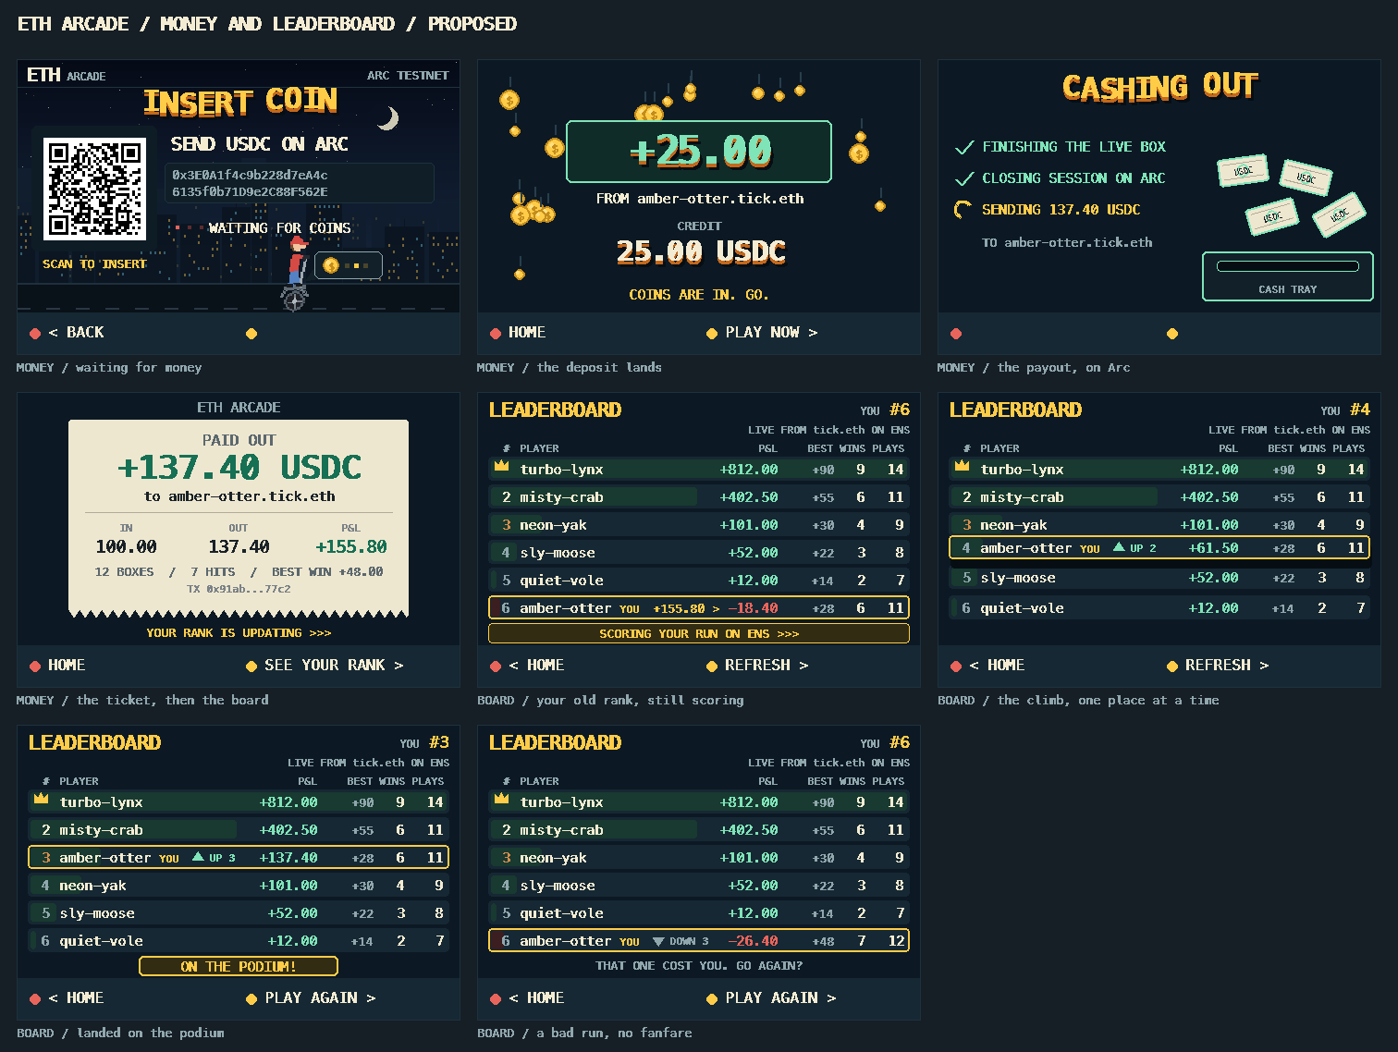
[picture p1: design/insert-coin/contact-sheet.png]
all the screens


---

## 1. I am on home and I want to play

I pick the money button and press A.

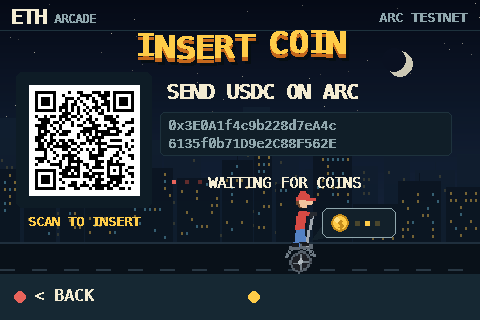
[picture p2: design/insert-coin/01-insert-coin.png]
insert coin


One QR code in a lit bezel, `SEND USDC ON ARC`, `WAITING FOR COINS`, the
address. That is everything. No cash-out wording, no balance, no house rules —
none of that applies until money is in. The game's own city is behind it, and
the kid on the wheel is the waiting sign: parked on the street, holding his
balance, thinking about a coin nobody has sent yet. Both sets of dots blink.

## 2. The money lands

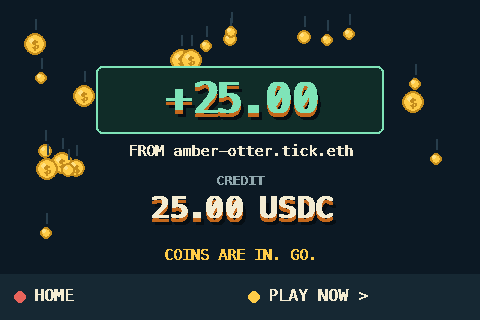
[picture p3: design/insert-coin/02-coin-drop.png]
coin drop


Coins rain, the credit counts up, the yellow button says **PLAY NOW**.

## 3. I press A and I am in the game

No detour through home. *(Today it drops me on the launcher with PLAY selected;
going straight in is the change.)* If I press nothing for 3 seconds it falls
back to home with PLAY selected, so nothing is forced on me.

## 4. I finish and I want my money

I press the money button, which already reads `CASH OUT · 137.40` on the
launcher. There is **no in-between screen** — the press starts the payout.

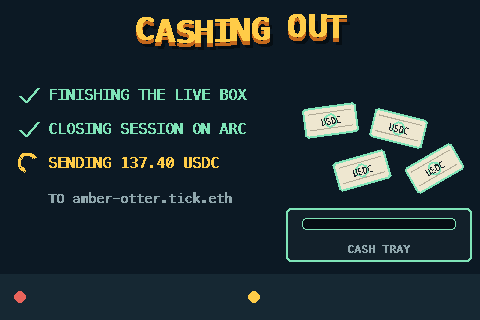
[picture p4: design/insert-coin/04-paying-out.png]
paying out


Three steps tick off while Arc confirms, and paper money flies out of the cash
tray. The wait becomes the show instead of a status line.

## 5. The machine prints my ticket

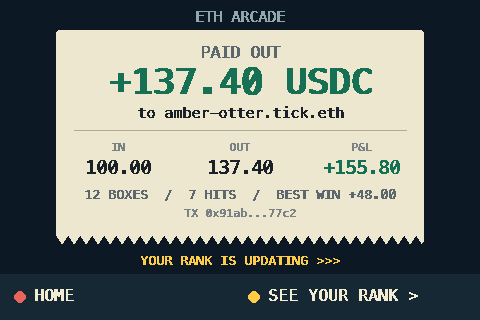
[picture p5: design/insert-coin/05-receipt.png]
receipt


In, out, P&L, boxes played, the tx. It reads `YOUR RANK IS UPDATING`, and after
2.5 seconds it takes me to the leaderboard by itself (or A goes now).

---

## 6. The board moves, one place at a time

I arrive still sitting at my **old** rank, with my pending result ghosted beside
my row and a strip saying the score is still landing.

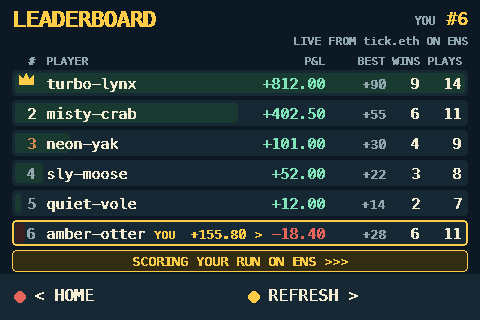
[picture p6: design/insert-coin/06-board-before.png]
before


> The scores live on ENS and the scorekeeper only writes them once the escrow
> closes, so there is a real few-second gap. The board holds the old picture
> and polls every 3 seconds instead of 20 rather than hiding it.

Then I climb **one row at a time** — not a jump. Each step is its own beat:
my plate lifts, the row above slides under me, the numbers roll, `UP 1` becomes
`UP 2` becomes `UP 3`, and my P&L counts up the whole way.

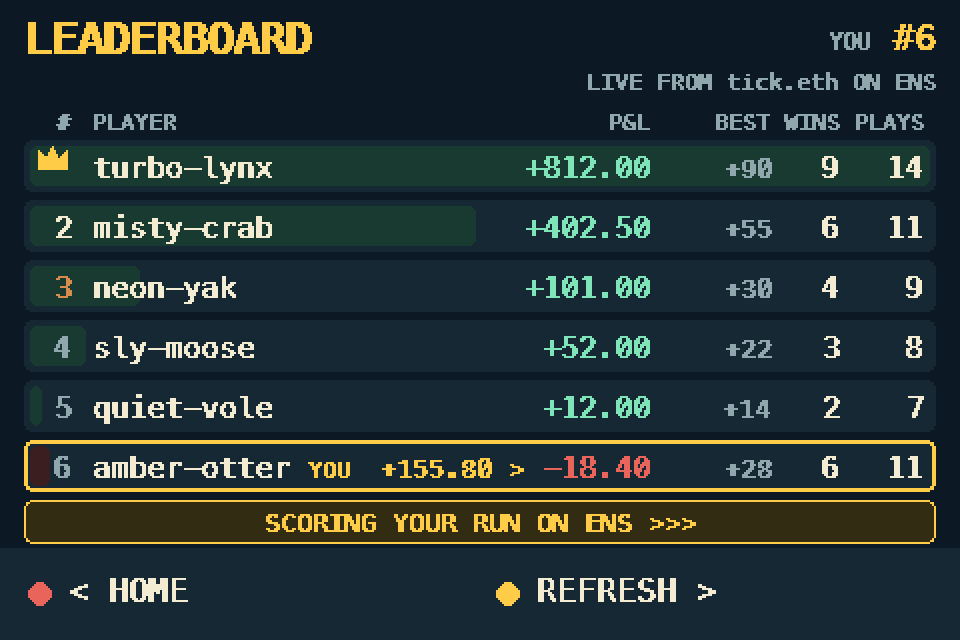
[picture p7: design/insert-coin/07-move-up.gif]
climbing


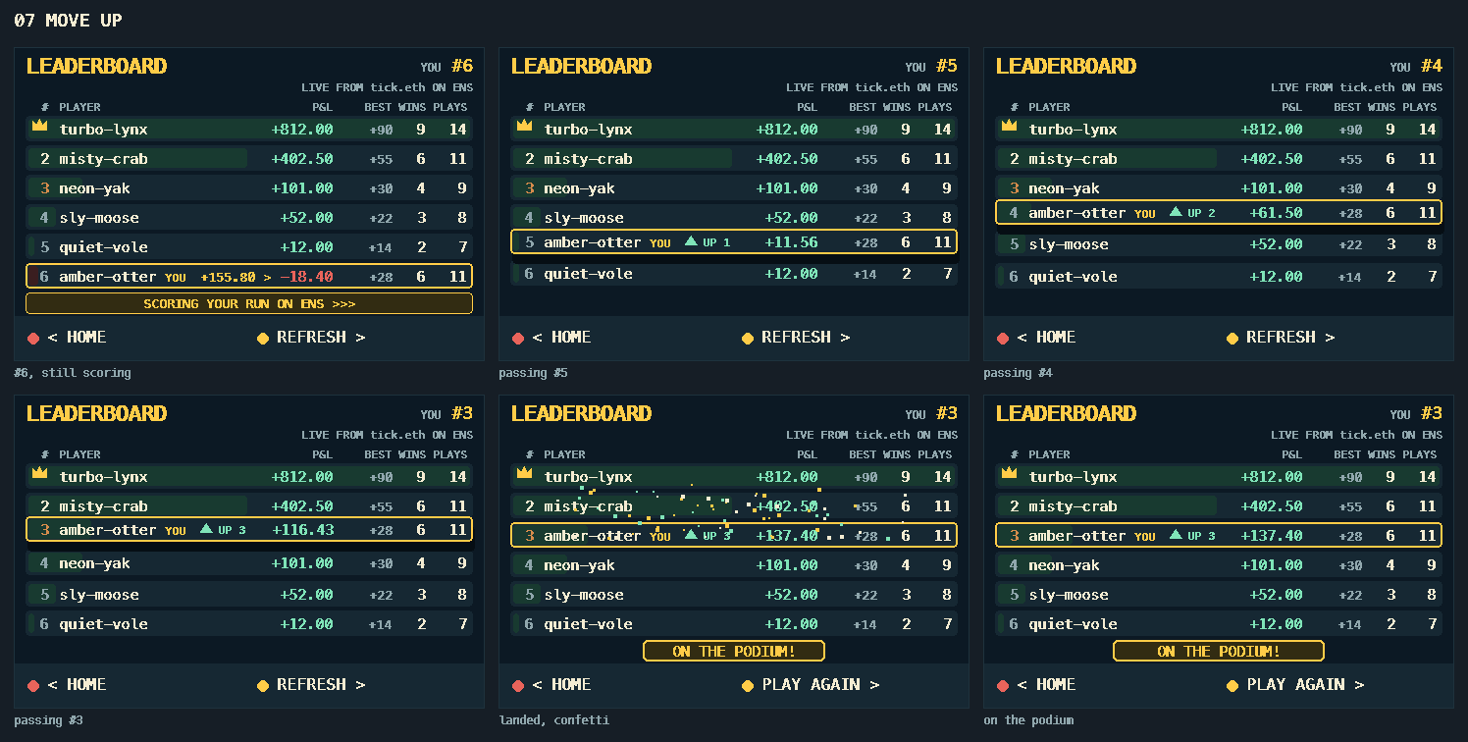
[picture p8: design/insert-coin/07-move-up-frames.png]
the climb as stills


Land on the podium and the machine celebrates: confetti off the plate, the
medal colour, `ON THE PODIUM!`.

If the run went badly, the same movement runs downward and **nothing
celebrates** — the rows slide, a grey `DOWN 3`, and a line that just asks if I
want to go again.

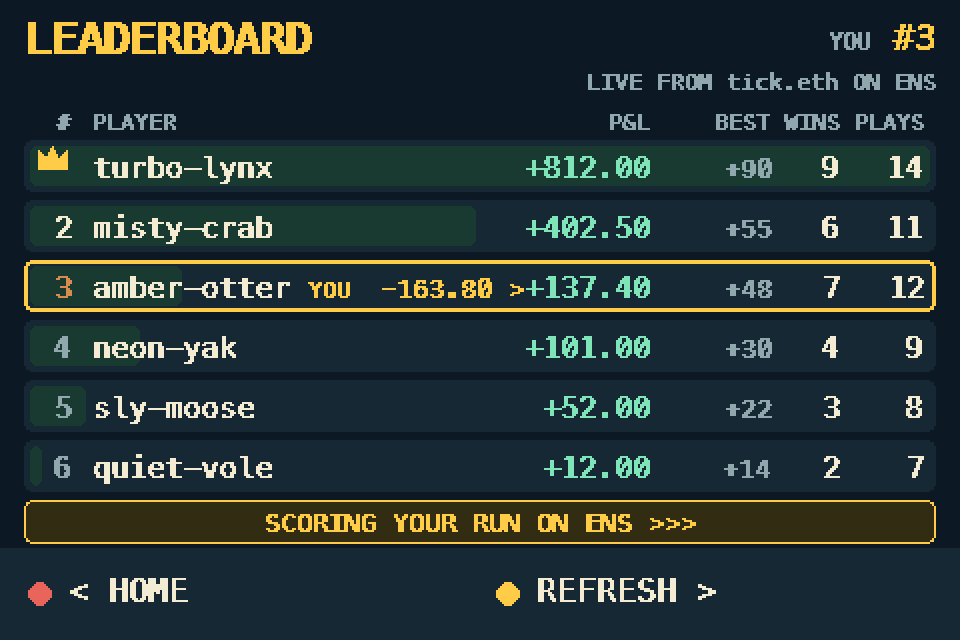
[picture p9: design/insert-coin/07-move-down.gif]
slipping


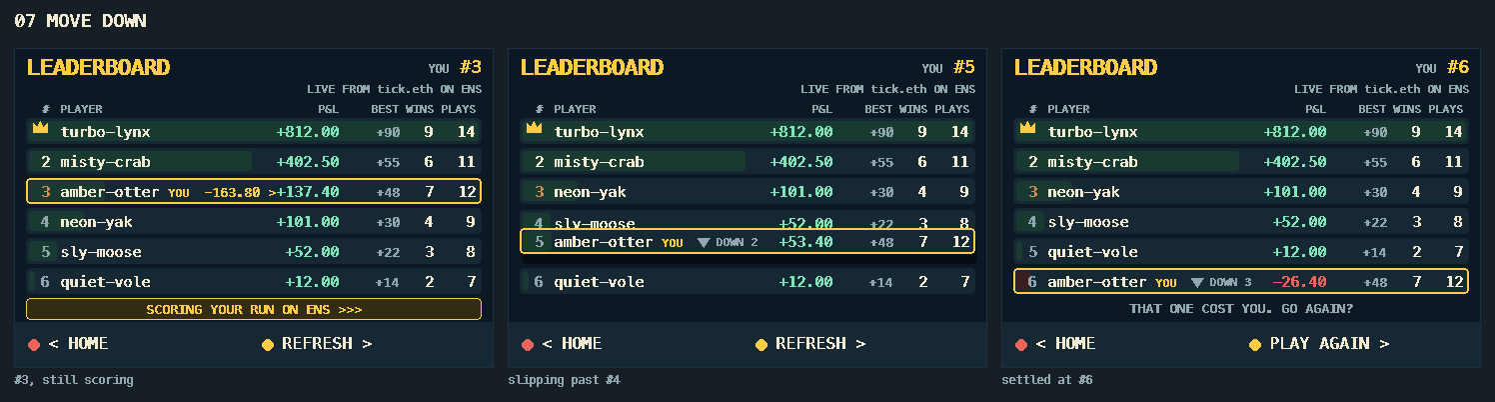
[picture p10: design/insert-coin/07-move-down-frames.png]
the slide as stills


Two cases worth their own moment, not drawn yet:

- **first ever run** — no old rank, so my row drops in from the top and stamps
  down as `NEW ENTRY`.
- **outside the visible six** — my row stays pinned at the bottom (it already
  does today) and the number itself counts `#12 → #9`, then flies up into the
  list if the climb carries me into it.

---

## The loop

```
   HOME ──A on the money button──► INSERT COIN
    ▲                                   │ deposit lands
    │                                   ▼
    │                              COIN DROP ──A = PLAY NOW──► BOX RUN
    │                                                             │
    │                                        A on the money button│
    │                                                             ▼
    │                                                        PAYING OUT
    │                                                             ▼
    │                                                         RECEIPT
    │                                                             │ A, or 2.5s
    └──────────────── B ───────────────────────────────── LEADERBOARD
                                                   old rank ▸ climb ▸ celebrate
```

---

## What changed from the last pass

- **Cut the bank page.** The screen that showed a big balance with the QR
  demoted to a chip is gone. Cash out fires from the launcher's money button,
  which already carries the balance.
- **Cut the podium still.** The celebration is the end of the movement, not a
  screen of its own.
- **The move is step-by-step**, one rank per beat, up or down, instead of a
  single swap.
- **Insert coin is a scene**, not a form: city, street, waiting rider, and only
  two lines of copy. The `10 USDC = ONE BOX` and `MAX WIN 5x` lines are gone.

## One thing to decide

Cutting the bank page means pressing the money button mid-session **sends a real
transaction with nothing in between**. That is fine if the press is deliberate,
but it is now the only screen-less irreversible action on the device. Either:

- leave it (fastest, matches how the button reads today), or
- make `PAYING OUT` start with a half-second `CASH OUT 137.40?` beat that a
  second press confirms — no extra page, just a beat at the top of the payout.

[SPEC.md](SPEC.md) has the implementation detail: which existing `ArcFunding`
field drives each screen, the animation timings, and the seven things the code
does not track yet — chiefly that the board must remember your previous rank and
hold the new rows back until the movement runs.

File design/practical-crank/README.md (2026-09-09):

# BOX RUN — practical crank appearance study

Two built-in imagegen renders: the white printed device in use, and a front/open-back packaging study. These are concept images, not photographs of a working device or verified CAD.

User constraints: two-day build, white filament with paint available, red and yellow buttons, side crank, Pi Zero 2 W, 3.5-inch display, tape assembly and no screws.

The proposed crank uses a short printed arm and integral finger peg to avoid implying that a bearing/bolt assembly is already available. The actual encoder shaft, attachment and side-load support must be measured and prototyped. Tape closes panels; internal ledges/cradles must take button and encoder loads. The open-back view is illustrative and is not a wiring diagram, pin map or proven component arrangement.

No dimensions or printable enclosure files are supplied because display PCB, connectors, switch bodies, encoder and cable clearance have not been measured. Keep the whole case white, paint only the screen surround charcoal, and use the existing red/yellow buttons. The current request is visualization; these images do not implement the approved game concept.

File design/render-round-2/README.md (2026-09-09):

# Render round 2 — printable TICK concepts

These are appearance studies for the two-day build, not dimensioned CAD or verified printable assemblies. Built-in imagegen generated the renders; prompts are saved alongside them.

## The three shells

| Direction | Character | Build approach | Main tradeoff |
|---|---|---|---|
| Cream Cartridge | Warm, nostalgic, friendly | Cream shell, flat charcoal bezel, orange caps | Rounded shell needs care with print orientation |
| Graphite Terminal | Crypto terminal / test instrument | Dark shell, pale faceplate, lime accents | Fine ribbing can add print time; keep it shallow and optional |
| Orange Sandwich | Bold, visibly assembled, maker aesthetic | Flat front and rear plates around orange middle frame | Seams and screws are visible by design |

**Recommended for two days: Orange Sandwich.** Its flat separate color pieces make the fabrication process part of the look. Cream Cartridge is the gentler aesthetic alternative. Use colors already available; no multi-material printer is required if parts are printed separately and assembled.

All three retain two large left-thumb buttons and a right-side crank. The crank arm and grip can be printed, but the axle and fastening should use available hardware. Measure the actual encoder and provide support against side loads. Rendered screws, clearances, internal packaging and exploded views are illustrative. Print a shaft/clearance coupon before a full shell; choose tolerances from the actual printer result.

For camera: use contrasting crank grip and body, a broad matte face, strong screen contrast, and a front-right view. Avoid depending on paint, concealed snap fits or a folding mechanism for the deadline.

## Four game directions

These are alternatives to select from, not a four-game implementation commitment.

### BOX RUN — most directly about trading

Crank positions a target price range. A advances center → width → confirm. At expiry, the selected observed price either lands in the committed box or misses. A narrow target earns more practice points. Keep its meaning consistent: expiry price, not any intermediate touch. Render shows the aiming/round scene. Build one 20-second loop; label replay or simulation explicitly.

### BLOCK DROP — strongest pure arcade loop

A crane carries ETH-shaped cargo over a stack. Crank moves it left/right; A drops, B cancels before release. Overlap determines the next platform's width. Every few blocks the background advances to a new exchange district. Crypto is initially the theme; don't claim each block is an onchain transaction. This is likely the simplest route to satisfying play in two days: no external price behavior is needed to make it fun.

### GAS RUN — most crypto-native metaphor

Queue a courier's transaction crate for the next block. Crank selects one of three fee lanes; A sends. A higher fee spends more practice credits but moves the crate forward. Goal: meet the delivery deadline with the most credits left. Use a defined simulated queue initially; this is a fee-market puzzle, not a promise about actual network inclusion. Needs more tutorial work than BLOCK DROP.

### NERVE — strongest character moment

Crank sets round intensity, then A/B counterbalance a courier on a bridge while market-inspired gusts blow. Falling is a game outcome, not a real liquidation. Existing repo sketch can help, but the current browser rendering still needs a device port. Keep the world playful and the risk label honest.

## Selection

For a trading-led product: Orange Sandwich + BOX RUN.
For the most immediately enjoyable physical toy: Cream Cartridge + BLOCK DROP.
For the two-day deadline, choose one of those combinations and defer the remaining games. Prototype crank response and one complete win/loss cycle before spending time on decorative screens.

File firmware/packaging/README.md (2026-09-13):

# Raspberry Pi app

Build on the target Raspberry Pi OS / Debian (requires python3-pip):

```sh
python3 firmware/packaging/build_deb.py --output dist
sudo apt install ./dist/tick-box-run_1.1.0_arm64.deb
```

The package bundles the Arc/ENS/QR libraries for the build machine's Python and
architecture. SDL/pygame and GPIO come from Raspberry Pi OS. No keys or local
settings are bundled. Launch **TICK BOX RUN** from Games or copy the executable
`/usr/share/applications/tick-box-run.desktop` to the Desktop folder.

Defaults are **Arc testnet USDC**, **live Coinbase ETH prices**, and **0.001 USDC
per press**. There is no starting paper balance or automatic simulated fallback.
Use LOAD USDC to fund the displayed device address.

Edit `~/.config/tick-box-run/.env` and relaunch to change settings:

```dotenv
TICK_FUNDING=arc-testnet
TICK_MARKET_SOURCE=coinbase
TICK_STAKE_USDC=0.001
# Optional: reuse an existing device wallet and saved session (absolute path).
# TICK_DATA_DIR=/home/jovian/tick-boxrun/.tick
```

To use paper play later, set `TICK_FUNDING=demo` and `TICK_MARKET_SOURCE=sim`.
Shell environment variables override the local file. `TICK_CONFIG_FILE` selects
an alternate config. New installations store their wallet under
`~/.local/share/tick-box-run/.tick`; keep this directory across upgrades.

Turn the dial to aim; yellow / dial click buys; red / long dial click returns.
Keyboard: Up/Down aim, Enter buys, Escape exits. Only one app instance runs at a
time. Logs: `~/.local/state/tick-box-run/game.log`.
Uninstall: `sudo apt remove tick-box-run` (wallet and settings remain).

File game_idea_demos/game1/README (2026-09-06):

NERVE — *the one people will remember*

**Verb:** crank to add position size. **A/B** to counterbalance. **Hold A** to cash out.

You're walking a beam. **Beam width is your liquidation distance** — crank up the size and the beam
narrows. Real price volatility shakes it, live. Distance walked accrues real P&L. Step off, you're
liquidated.

```
  NERVE                       ×4.0
              ░░
         ▄▄▄▄████▄▄▄▄
    ═════════╤╧╧╧╧╤═════════
            ╱  ╳  ╲            ← beam shakes with live ticks
   ▁▁▁▁▁▁▁▁▁       ▁▁▁▁▁▁▁▁
   PNL +$1.40   FEED 10Hz  ▓▓░ 21
```

This is where the concept earns its name. Market volatility stops being a chart and becomes a physical
sensation in your hands — and because the shake is driven by a **real, metered feed**, buying the cheap
1 Hz data means you feel the shake a second late and fall. That's the whole thesis of §2 delivered as
gameplay in about eight seconds of video.

**Real primitive:** a leveraged position with a real liquidation price.
**Sponsors:** Hedera (burns ticks fastest — best INSERT COIN moment), Privy (the cap is the hard floor
under a leveraged game, which is a *good* look), Arc.

---

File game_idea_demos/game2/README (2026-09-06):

LONGSHOT — *charge and release*

**Verb:** crank to charge a power bar. **Release A** to commit.

The classic Track & Field / golf power meter, except the bar is **distance price must travel** and the
payout scales with how far you cranked. Over-crank and you'll never touch it.

```
  LONGSHOT
   ┌────────────────────────────┐
   │████████████████░░░░░░░░░░░░│  +1.4%
   └────────────────────────────┘
        HOLD A · RELEASE TO FIRE
              PAYS 6.8x
```

**Real primitive:** a one-touch / knock-in option — *does price touch +X% within 60s?* A genuine exotic,
and the power bar is the most natural interface anyone has ever put on one.

---

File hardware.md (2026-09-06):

# Hardware

Pin map for this handheld: [Waveshare 3.5inch RPi LCD (F)](https://www.waveshare.com/wiki/3.5inch_RPi_LCD_(F)) plus a KY-040-style rotary encoder on a Raspberry Pi 5.

All GPIO numbers below are **BCM**. Board pins are the 40-pin header positions.

## Display — 3.5inch RPi LCD (F)

- Panel: IPS, native **320×480** (firmware runs landscape **480×320**)
- LCD controller: **ST7796S** over **SPI0**
- Touch controller: **GT911** (Goodix) over **I2C**, overlay `goodix` at `0x5d`
- Power: **5V** panel supply, **3.3V** logic

Wiring matches the Waveshare cable pinout, with one change: **backlight is on GPIO12 instead of GPIO18**.

| Function | BCM | Board pin | Notes |
|---|-----|---|---|
| VCC | 5V | 4 | Panel supply |
| GND | GND | 6 | |
| MISO | 9 | 21 | SPI0_MISO |
| MOSI | 10 | 19 | SPI0_MOSI |
| SCLK | 11 | 23 | SPI0_SCLK |
| LCD_CS | 8 | 24 | SPI0_CE0 |
| LCD_DC | 22 | 15 | Data / command |
| LCD_RST | 27 | 13 | Reset |
| LCD_BL | **12** | **32** | **Moved from Waveshare default GPIO18 / pin 12** |
| TP_SDA | 2 | 3 | I2C1 SDA |
| TP_SCL | 3 | 5 | I2C1 SCL |
| TP_INT | 4 | 7 | Touch interrupt |
| TP_RST | 17 | 11 | Touch reset |

### Diff vs Waveshare wiki

| Signal | Waveshare default | This device |
|---|---|---|
| LCD_BL | GPIO18 (board pin 12) | **GPIO12 (board pin 32)** |

Everything else matches [Method 2: Connect Raspberry Pi through Cable](https://www.waveshare.com/wiki/3.5inch_RPi_LCD_(F)#Method_2:_Connect_Raspberry_Pi_through_Cable).

### Matching `/boot/firmware/config.txt` fragment

```text
dtparam=spi=on
dtoverlay=mipi-dbi-spi,speed=48000000
dtparam=compatible=st7796s\0panel-mipi-dbi-spi
dtparam=width=320,height=480,width-mm=49,height-mm=79
dtparam=reset-gpio=27,dc-gpio=22,backlight-gpio=12
dtoverlay=goodix,addr=0x5d
```

## Rotary encoder

Typical KY-040-style module. Logic at **3.3V only** (do not power from 5V).

| Encoder pin | BCM | Board pin | Role in firmware |
|---|-----|---|---|
| VCC | 3.3V | 1 or 17 | Module power |
| GND | GND | 9 (or any GND) | Ground |
| SW | 16 | 36 | Push button — short = A, hold ≈0.65s = B |
| DT | 20 | 38 | Quadrature B |
| CLK | 21 | 40 | Quadrature A |

Firmware mapping (`firmware/encoder.py`):

| Input | Action |
|---|---|
| Turn | Navigate UP / DOWN |
| Short click | A (launch / select) |
| Hold click | B (back / quit) |

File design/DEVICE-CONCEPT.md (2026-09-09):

# TICK — a pocket market arcade

Design proposal • 9 September 2026 • Working name, not cleared branding.

**Pitch:** Turn a physical crank to play with markets. Two buttons, one tiny screen, and a visible receipt for the onchain action.

The strongest submission is one memorable physical interaction, one excellent game, and one verifiable financial flow. Build NERVE as the hero using the existing sketch, with LONGSHOT as the second cartridge only after the hero works on the actual device. A wide catalogue would weaken the demo.

## What exists and what is proposed

The repository has a pygame launcher at 480×320, a GPIO rotary encoder, and browser sketches of NERVE and LONGSHOT at 400×240. Both sketches generate market movements locally; sponsor names in their logs are not evidence of integrations. Their mathematical models are game prototypes, not production trading engines.

`hardware.md` describes a Waveshare LCD (F) and Pi 5. This proposal targets the user's Pi Zero 2 W. Treat the recorded wiring as a starting point to verify, not an already-tested Zero configuration. The display model still needs confirmation.

## Physical object

Choose a warm cream shell, charcoal bezel, persimmon-orange A button and crank grip. Mint is the screen's success color; amber is attention. This looks like a cherished pocket instrument and makes the moving orange crank easy to see on camera. Avoid glossy finishes, tiny decorative text and thin scanlines.

Provisional envelope: **124 W × 112 H × 30 D mm**, excluding crank. These are packaging targets, not fabrication dimensions. Measure the panel PCB, connectors, cable bends and mechanical stack before CAD. A 3.5-inch 3:2 active area is approximately 74×49 mm; its board may be substantially larger.

| Part | Proposed design | Reason |
|---|---|---|
| Display | Landscape, centered in upper face; matte charcoal surround | Large scene, readable while cranking |
| A/B | Two 15–17 mm caps, about 23 mm center spacing, together at lower left | Left thumb operates both while right hand cranks |
| Home | One small recessed button lower right | Avoid accidental exits; no overloaded A/B hold gestures |
| Crank | Right side, roughly 20–22 mm throw, free-spinning grip | Recognizable silhouette and satisfying winding action |
| Rear | Rounded palm surfaces, service screws, cable strain relief | Comfortable hold and repairability |
| Audio | Small speaker with short bottom slots; amplifier module | Clicks and reward tones reinforce touch |
| Power | Cable-powered first build; rear cable exit | Keeps the first enclosure achievable |

Use a bearing-supported shaft or supported crank bracket so side loads do not bear directly on the encoder module. A basic detented encoder is fine for the first knob prototype; test before using it as a fast crank. Prototype an open arm before attempting a folding hinge. Verify the complete sweep with real fingers: no collision with enclosure, tabletop, cable or left hand. Support the shell with the left palm; test with both small and large hands. Offer a reversed rotation setting.

**Do not add a D-pad or separate knob in v1.** The crank handles menu selection and game adjustment. More controls add wiring, visual clutter and learning time. Make an interchangeable knob cap for development, with the crank as the final hero control.

Optional GPIO proposal, subject to checking the actual overlays: A=GPIO5, B=GPIO6, Home=GPIO13, active-low buttons to ground with pull-ups. Keep existing encoder GPIO21/20/16. These do not overlap the panel pins recorded in `hardware.md`; audio or later peripherals can change that. Keep encoder logic at 3.3V. Drive speakers/haptics through appropriate modules, not directly from a GPIO. Do not finalize a battery or charging design until packaging and power draw are measured.

## The controls must tell the truth

Global: turn to select, A to enter/confirm, B to back/cancel, Home to return to launcher after resolving any active round. During play, returning home must not silently cancel a pending financial operation.

Cranking changes a preview immediately. Financial changes require a clearly labeled confirmation; never send one transaction per encoder edge. Show the accepted value separately while an operation is pending. Every screen has two persistent A/B hints, and the launcher teaches the crank with a short looping animation.

The current encoder converts motion into throttled menu UP/DOWN events. Add a separate signed rotation-delta input for games, plus explicit button-down/up states. Never reuse the menu's queued navigation as a gameplay motion signal: the character could keep moving after the player stops turning. Timestamp inputs, cap unreasonable deltas, and test reversals under fast spinning.

## Game lineup

| Game | Physical interaction | Why it works | Priority |
|---|---|---|---|
| NERVE | Crank sets intensity before a round; A/B balance during play | A tiny courier on a beam is legible and expressive immediately | Hero |
| LONGSHOT | Hold A and wind to aim; release to lock a preview; A confirms | Slingshot-like ritual with a visible target and payoff | Second |
| BOX RUN | Crank moves a price box; A fixes center then width; B resets | Clear interpretation of “box trading”: predict a price range at expiry | Alternative to LONGSHOT |
| MARKET MAKER | Crank positions a band; A changes width; B collects a practice result | Turns liquidity-range management into a tactile puzzle | Later |
| SWAP SHOP | Crank selects quantity; A reviews quote then confirms; B cancels | A useful trading utility and straightforward real financial-flow demo | Optional integration fallback |

### NERVE: preserve the fun, repair the metaphor

The existing game mixes price exposure with player-controlled wobble. A/B cannot magically prevent a real leveraged position from liquidating. For the hackathon, recommend **a clearly labeled practice game driven by market data**, with actual onchain payment for access/data and a verifiable receipt. The game score and payment are separate facts.

Round: select practice intensity → confirm → play for 30 seconds → show score → show receipt. A/B move the courier's balance; market returns animate gusts; intensity narrows the beam. Use a clear practice score, not fictional dollar profit. The crane/beam world should feature a tiny courier, blocks, warning lamps and one expressive fall animation.

If real positions become essential, scope a different mode: crank previews exposure, A submits a change, B requests a reduction/close, and the beam displays actual venue risk. Remove manual balance that changes liquidation. Use venue-confirmed position, fees, margin and liquidation data; the current approximate `1/leverage` model is insufficient. Do not advertise this mode until an execution venue is integrated and tested.

### LONGSHOT and BOX RUN

Keep both as practice predictions initially. LONGSHOT asks whether a defined observed price crosses a threshold during a specified interval. BOX RUN asks whether the expiry price lands in a chosen range. These are different settlement rules. In a real-money version, terms must define the source, timestamps, sampling, boundary equality, stale-feed behavior, payout funding and disputes. A sampled oracle cannot establish every unsampled market touch; label it as observed crossings at the specified samples.

Do not call the sketch's simulated multipliers executable quotes. For the hero demo, a deterministic replay gives a reliable dramatic sequence, with a persistent REPLAY label. Live mode must actually consume live data and show its age. Stop new commitments on stale data; never let visual animation imply fresh prices.

## Screen design at 480×320

Use a full-color pixel world with clean UI text. Reserve roughly 28 px for status and 36 px for controls; let the main scene own the rest. Main numbers should be 28–36 px, primary labels 18–22 px, secondary labels at least 16 px, validated on the physical panel. Touch targets should be about 48 px or larger where possible. Use words and shapes alongside colors.

Three core screens are illustrated in `screen-studies.svg`: cartridge selection, NERVE practice, and receipt. These are exact 480×320 composition studies, not running firmware. The product rendering is an aesthetic concept, not a dimensioned engineering drawing.

Do not stretch 400×240 game canvases into 480×320: their aspect ratios differ. Recompose the scene to the native screen. Nearest-neighbor scaling should apply to sprite artwork; UI text needs its own native-resolution rendering.

States: BOOT → HOME → REVIEW → PLAY → RESULT → RECEIPT. Financial operations separately track READY → SUBMITTING → PENDING → CONFIRMED/FAILED. A confirmed chime plays only after actual confirmation. Repeated taps and retries must not create duplicate purchases.

## Architecture and feasibility

Keep pygame on the Pi. Port only the selected game's mechanics, using a renderer-independent state model. Avoid adding a browser kiosk until a device benchmark justifies it. The Zero 2 W has a quad-core CPU and 512 MB RAM; budget conservatively ([official product specifications](https://www.raspberrypi.com/products/raspberry-pi-zero-2-w/)).

```text
Buttons / encoder / touch
          ↓
Input adapter → game state → pygame renderer → SPI display
                    ↕ asynchronous messages
              authenticated backend
               ↙             ↘
       market-data adapter   wallet / payment adapter
                                  ↓
                          actual chain receipt
```

Network work never blocks the frame loop. The Pi receives minimal game/feed state; the backend handles authenticated payment intents and deduplication. Pair by a short-lived QR session on the phone. Restrict authorized spend, recipient, expiry and replay; enforce those limits in the backend/wallet controls rather than trusting the device UI. Do not put a master wallet secret on the Pi image.

The repository requests a 48 MHz SPI bus. At 480×320×16 bits, 30 complete frames/s would require about 73.7 Mbit/s before overhead. So 30 displayed full-screen updates/s cannot be assumed at that bus rate. Benchmark actual transfer behavior first: target responsive controls, small dirty regions and modest animation; verify whether the driver benefits from partial updates. Fall back to 15–20 displayed updates/s if necessary while keeping input responsive. Avoid full-screen camera shake, which invalidates most pixels.

## Sponsor strategy

I found the [official ETHOnline 2026 prize list](https://ethglobal.com/events/ethonline2026/prizes). Provisional fit: Hedera's x402 track requires a live gated service through Blocky402 and a real paid request. Privy's financial-flow track requires a wallet and a functional flow; login alone is insufficient. Arc is an alternative for meaningful USDC finance. Confirm chain/provider compatibility before combining them. Pick one primary integration, then one complementary sponsor only if time permits.

Proposed hero flow: authorize a bounded session → purchase a round/data entitlement → play NERVE → open the real payment receipt. Payment unlocks actual service delivery. One purchase per round is easier to demonstrate than pretending to settle every animation tick. Resolve pricing and facilitator support in an early integration spike.

Before submitting, verify event eligibility for pre-existing code and disclose the starter work. The existing repo is a useful base, not proof that all of it was built during the event.

## Build sequence and exit criteria

Timing is provisional until the deadline and team size are known. Work in this order:

1. **Hardware spike — half day.** Boot actual Zero with display/touch; measure refresh, input latency and crank edge loss. Print a full-scale paper faceplate and make a cardboard grip/crank mockup. Exit: two people can play without changing grip awkwardly.
2. **Vertical slice — one day.** Port one NERVE round, add proper input events, launcher, result and sounds. Exit: complete 20 rounds without crash or stuck input, at readable brightness.
3. **Integration spike — one day.** Deliver one real authorized payment and actual purchased service, then receipt. Exit: verify transaction independently; handle rejection, timeout and duplicate button presses.
4. **Enclosure and polish — one day plus fabrication lead time.** Fit boards, strain relief and supported crank; sand/finish shell, add simple labels. Exit: 30-minute session without loose mechanism or thermal/power faults.
5. **Demo rehearsal — half day.** Film, verify submission evidence, prepare explicitly labeled replay and connection recovery. Add second game only if all previous exits pass.

If time collapses, cut battery, folding crank, haptics, second game and extra sponsors. Preserve the physical crank, hero game and one real payment flow. Do not order a full enclosure before measuring the exact display assembly.

## Camera and judging plan

Opening line: **“We built a pocket market arcade. Turn the crank, play a round, and see exactly what the device paid for.”**

- 0–10s: macro of crank and audible button press, then full device in hands.
- 10–30s: select NERVE, show the bounded purchase and begin play.
- 30–60s: one complete round, large visual tension, satisfying result.
- 60–80s: real receipt and the corresponding explorer/backend evidence.
- 80–110s: simple architecture and why programmable payment matters.
- Final seconds: another person picks it up and understands the controls.

Film from front-right so the crank remains visible. Use diffuse light, lock exposure/focus and test shutter settings against screen flicker. Use large sprite motion, short tones, stable UI and minimal glare. Capture a direct screen recording alongside the physical shot, but show the actual device working. Never present replay as live or pending as confirmed.

Success measures: understandable interaction within 10 seconds; complete playable round within 30 seconds; visible button feedback targeted under 100 ms and measured; no stuck input; no duplicate purchases; one independently verifiable transaction; legible screen in the final camera framing.

## Remaining decisions

Confirm sponsor priorities, deadline/team, exact display model, fabrication access and whether genuine trading positions are essential. Default recommendation: physical NERVE practice arcade with real paid data/access. Keep the proposed trading modes in the design, but earn the live-finance claim with an actual supported integration.

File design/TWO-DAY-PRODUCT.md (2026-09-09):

# TICK — two-day product direction

This supersedes the scope and priorities in DEVICE-CONCEPT.md. Deadline: two days. Enclosure and control caps: 3D printed. Product first; prize targeting deferred.

## Product

A tiny crypto trading arcade, styled like a pocket terminal from an alternate 1989. The screen is a miniature exchange: pixel candles, ETH-shaped cargo, block-height counters and a courier working the night shift. Physical winding is the signature interaction.

Keep the cream, charcoal and orange physical direction. Use filament colors for the finish: cream body, separate charcoal bezel, orange button caps and crank grip. Mint/amber/red live on the display. Print a small raised TICK wordmark, not fine engraved paragraphs. No paint-dependent finish, folding crank, battery development or extra controls in the critical path.

## One cartridge: BOX RUN

Recommendation for the deadline: one price-box prediction game. It gives the crank a continuous, obvious role and makes the crypto theme understandable without explanation. NERVE remains an existing prototype to reuse or revisit, not a second required deliverable.

The screen has a price trace on the left and a target box at a fixed expiry line on the right. Vertical position means price; horizontal movement means time. A ghost candle shows where the latest observed price would land. The interaction is:

1. Turn the crank to move the target box up/down relative to the current ETH price.
2. Hold B while turning to change its width. A thinner box earns more practice points; always display the points before committing.
3. Press A to lock the prediction and start a 20-second round. No purchase occurs merely by rotating.
4. During the round, the crank scrubs the already-observed trail; releasing it returns to the latest price. The committed box never moves. B returns immediately to the latest view. A has no trading action while locked.
5. At expiry, the selected observed price lands inside or outside the box. A hit stamps a pixel block onto a small tower; a miss cracks it. Show one large result and A AGAIN / B HOME.

The width modifier needs a prominent B + TURN hint and a brief first-run tutorial. If simultaneous input support takes too long, use A to advance CENTER → WIDTH → LOCK, with B back. Choose the latter for the first implementation because the current input layer lacks explicit held-button events. Two front buttons plus crank are enough.

Use practice points initially. Labels distinguish LIVE DATA, REPLAY and SIMULATED. A blockchain-shaped icon is thematic; a verified transaction is a separate implemented feature. Never imply that simulated points are tokens or settled funds. If actual trading is required, decide that before writing a settlement system: it changes the two-day scope materially.

## Print-friendly construction

Print a shallow front shell and removable rear cover; use accessible screws and available inserts or an appropriate self-tapping design. Avoid unsupported large bridges, fragile clips, hidden fasteners and cosmetic grooves that demand post-processing. Orient the visible face for the best available printer finish. Choose wall thickness, clearance and support based on the actual printer/material and a small fit coupon, not an assumed universal tolerance.

Measure the display PCB and mounting holes, Pi/header stack, wires and encoder before the first enclosure print. Use the earlier 124×112×30 mm only as a rough envelope. Position both buttons lower left and the crank shaft on the right, with clearance for the complete handle sweep. Print a faceplate and crank coupon first; hold them in both hands before committing to the shell.

Use a short rigid crank arm with a separate freely rotating grip secured by available screw/shaft hardware. Support the rotating shaft against side loads. The arm and grip can be printed; do not assume a printed bearing or encoder PCB alone is a durable mechanical support. Keep an ordinary printed knob as the fallback. A smooth knob that works is preferable to a crank that binds during the demo.

Cable power, strain relief and a serviceable rear cover are v1. Sound is optional if the speaker hardware is already available. Skip custom haptics and battery charging work.

## Two-day schedule

Hours are elapsed planning blocks, adjusted for printer time and sleep. Start physical measurements immediately; print while developing software.

- First 3 hours: freeze the screen and controls; measure parts; make fit coupon/faceplate; test panel refresh and encoder input.
- Rest of day 1: implement CENTER → WIDTH → LOCK → ROUND → RESULT; deterministic labeled demo data; start first enclosure print; assemble and test grip.
- First half of day 2: fit corrections and final print; add a real read-only crypto price source if feasible; refine text, sprite animation and result sound. Preserve working replay mode.
- Final half of day 2: stop adding features; assemble, run repeated rounds, verify reconnect/restart behavior, film the physical demo and package the code.

Definition of done: powers up into one playable crypto-themed game; every control is understandable; crank motion is immediately visible; enclosure survives repeated handling; screen reads on camera; full round works reliably; data mode is honestly labeled.

## Visual direction

Launcher: a large pixel ETH cargo crate and BOX RUN title, with TURN TO AIM / A START.

Game: dark navy exchange floor; cream price trail; mint target outline; amber time strip. Large 20s countdown. No tiny candlestick dashboard, wallet address or sponsor logos in the play area.

Result: BLOCK LANDED or OUT OF RANGE, score, a stamped block added to the tower, and restart. Avoid calling the result a mined or confirmed blockchain block unless that event actually exists.

Opening demo sentence: “This is TICK. You crank a prediction into place and watch the crypto market land inside it—or miss.”

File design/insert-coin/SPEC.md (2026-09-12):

# Money and leaderboard: flow redesign

> **Superseded in part by [README.md](README.md) and the mockups beside it.**
> That later pass cut the bank face (cash out now fires straight from the
> launcher's money button), dropped the podium as a separate screen, and made
> the leaderboard move one rank per beat rather than in a single swap. The
> analysis of what is wrong today, the state table, the timings and the list of
> what the code does not track yet all still hold — read them here, but take the
> screen list from the README.

The game is done and it is fun. The two screens around it are not. This is a
design proposal for both — the money screen (`BoxGame.draw_arc_wallet`) and the
leaderboard (`screens/board.py`) — plus the flow that joins them. Nothing here
is built yet; it is written to be argued with.

---

## 1. What is wrong today

### The money screen does three jobs in one layout

```
 ┌──────────────────────────────────────────────────┐
 │ ┌──────────────┐  SEND USDC ON                   │
 │ │              │  ARC TESTNET                    │
 │ │   QR 164px   │  0x3E0Axxxxxxxxxxxxxxxxxxx      │   <- deposit job
 │ │   always     │  xxxxxxxxxxxxxx562E             │
 │ │   the hero   │                                 │
 │ │              │  WAITING FOR USDC...            │   <- status job
 │ └──────────────┘  KEEPS 0.01 OF EACH FOR GAS     │
 │                                                  │
 │  BALANCE 137.40 USDC                             │   <- bank job
 │  CASH OUT GOES TO amber-otter.tick.eth           │
 ├──────────────────────────────────────────────────┤
 │ < BACK                            CASH OUT >     │
 └──────────────────────────────────────────────────┘
```

- The QR is the largest thing on screen **even when you already have money in
  and the only thing you want is to cash out**. The screen keeps shouting "send
  USDC" at a player who is trying to leave.
- Three different truths about the same money are in three places: the address
  block (deposit), the 26-character status line (network), and the bottom two
  lines (balance / payout). None of them is clearly the headline.
- Money arriving is the best moment the device has, and it is a 6-second text
  banner.
- Cashing out is a dead end. The transaction lands, a line of text changes, and
  you are still looking at a QR code that says SEND USDC ON ARC TESTNET. No
  receipt, no summary of the run, nothing to do next.

### The leaderboard is a spreadsheet

Rows arrive, your row glows yellow, nothing ever moves. The single most
interesting fact — *you just went from 4th to 3rd* — is never shown, because the
board has no memory of where you were before.

### The flow has two dead ends

```
   HOME -> money screen -> (deposit lands) -> HOME          [ok, PLAY is focused]
   HOME -> BOX RUN -> money screen -> CASH OUT -> ...still on the QR screen
                                                  B, scroll, A to find LEADERS
```

---

## 2. The flow we want

```
        ┌────────────────────────────────────────────────────────┐
        │                                                        │
   ┌────▼─────┐  A on money button                               │
   │   HOME   ├──────────────► ┌─────────────┐                   │
   │ attract  │   (no funds)   │   MONEY A   │  SCAN TO PLAY     │
   └────▲─────┘                │   waiting   │  big QR           │
        │                      └──────┬──────┘                   │
        │                             │ deposit lands            │
        │                      ┌──────▼──────┐                   │
        │  timeout 3s          │   ARRIVAL   │  coins rain,      │
        ├──────────────────────┤  +25.00 !!  │  balance counts   │
        │                      └──────┬──────┘                   │
        │                             │ A = PLAY NOW             │
   ┌────▼─────┐                       │                          │
   │ BOX RUN  │◄──────────────────────┘                          │
   │  (game)  │                                                  │
   └────┬─────┘                                                  │
        │ A on money button (in session)                         │
   ┌────▼─────┐                                                  │
   │ MONEY B  │  THE BANK: balance is the hero, QR is a 64px     │
   │  in play │  chip marked ADD MORE. A = CASH OUT.             │
   └────┬─────┘                                                  │
        │                                                        │
   ┌────▼─────┐   three ticking steps, armoured truck drives     │
   │  PAYING  │   across the street while Arc confirms           │
   └────┬─────┘                                                  │
   ┌────▼─────┐   PAID OUT +137.40, session summary, tx          │
   │ RECEIPT  │   A = SEE YOUR RANK, or auto after 2.5s          │
   └────┬─────┘                                                  │
   ┌────▼─────────────────┐                                      │
   │ LEADERBOARD (arrival)│  opens at your OLD rank, waits for   │
   │  #4 ──────► #3  ▲    │  the scorekeeper, then MOVES you     │
   └──────────┬───────────┘                                   B  │
              └──────────────────────────────────────────────────┘
```

Two rules carry the whole thing:

1. **One screen, one job.** The money screen changes shape with the state of the
   money instead of showing all three states at once.
2. **Money moving is an event, not a status line.** Arriving and leaving both get
   their own beat, and leaving hands you straight to the leaderboard.

---

## 3. The money screen

Same 480x320 canvas, same palette (`ui.py`), same footer band. Which of the four
faces is drawn comes from the funding state that already exists on
`ArcFunding` — no new chain plumbing:

| face | condition (already available) |
|---|---|
| A · WAITING | `not funding.in_session and funding.last_cashout is None` |
| ARRIVAL | on the `('opened', amount, sender)` event from `funding.sync` |
| B · BANK | `funding.in_session` |
| PAYING | `self.cashing or funding.pending_cashout is not None` |
| RECEIPT | `funding.last_cashout is not None and not in_session` |

### A · WAITING — the only face where the QR is the hero

```
 ┌──────────────────────────────────────────────────┐
 │ ETH ARCADE                          ARC TESTNET  │ 6
 │                                                  │
 │  ┌────────────────┐                              │
 │  │▓▓░▓░░▓▓▓░▓▓░▓▓▓│   SCAN TO PLAY               │ 46  24px YELLOW
 │  │▓░▓▓▓░░▓░▓░░▓░░▓│   Any amount of USDC on Arc  │ 72  13px MUTED
 │  │▓▓░░▓▓▓░▓▓▓░░▓░▓│                              │
 │  │══════scan══════│   0x3E0A 1f4c 9b22 8d7e      │ 104 15px CREAM
 │  │▓░▓░░▓▓░░▓░▓▓▓░▓│   ...  ...  ...  562E        │ 124
 │  │▓▓▓░▓░░▓▓░▓░░▓▓▓│                              │
 │  └────────────────┘   ● WAITING FOR USDC ...     │ 160 15px CREAM, pulse
 │   14,40  180x180                                 │
 │                       10.00 USDC = ONE BOX       │ 186 13px MUTED
 │      (o_o)/                                      │
 │      _|_|_   <- rider, empty bucket held out     │ 214
 │                                                  │
 │  MAX WIN 5x YOUR DEPOSIT  ·  0.01 KEPT FOR GAS   │ 250 11px MUTED
 ├──────────────────────────────────────────────────┤ 274
 │ ● < BACK                                         │
 └──────────────────────────────────────────────────┘
```

- A **scan beam** sweeps down the QR every 2s. It costs one `draw.line` and it
  makes a dead screen breathe.
- The **rider from the game stands at the bottom holding a bucket** (reuse
  `box_scene.Rider`, already imported by the launcher). This is the one screen
  in the product where our mascot has nothing to do, so let it look bored:
  taps foot, checks an imaginary watch after 15s.
- The address is split into readable quads, not two dense 22-char runs.
- The footer has no A action here. Nothing to press means nothing to press
  wrongly.
- Error state replaces the status line only: `● ARC UNREACHABLE — RETRYING` in
  RED. The QR stays valid, so do not hide it.

### ARRIVAL — 2.5 seconds, the best moment we own

Triggered by the existing `'opened'` event. Full-screen takeover.

```
 ┌──────────────────────────────────────────────────┐
 │       o     o      o        o     o              │  coins fall from the top
 │   o        o    +25.00 USDC     o        o       │  into the rider's bucket
 │        o      ╔══════════════╗       o           │  (Sparks + Floaters,
 │            o  ║   40px MINT  ║   o               │   both already exist)
 │               ╚══════════════╝                   │
 │            FROM amber-otter.tick.eth             │  or short address
 │                                                  │
 │              BALANCE  25.00 USDC                 │  counts up 0 -> 25
 │                                                  │
 │              \(^o^)/   rider cheers              │
 ├──────────────────────────────────────────────────┤
 │ ● HOME                        ◆ PLAY NOW >       │
 └──────────────────────────────────────────────────┘
```

- Sound: existing `coin` cue, then the buy arpeggio.
- **A goes straight into BOX RUN.** If nobody presses anything for 3s, fall back
  to the launcher with PLAY focused — which is exactly what the `funded` return
  value already does today. One press from wallet to playing.
- A second deposit while already in session re-plays this shorter (1.2s) and
  returns to face B rather than home.

### B · BANK — money in, the QR gets out of the way

```
 ┌──────────────────────────────────────────────────┐
 │ ETH ARCADE                 amber-otter.tick.eth  │ 6
 │                                                  │
 │  BALANCE                             ┌────────┐  │ 40  13px MUTED
 │  ╔════════════════════╗              │▓░▓░▓░▓▓│  │
 │  ║   137.40 USDC      ║              │░▓▓░▓▓░░│  │ 56  34px CREAM
 │  ╚════════════════════╝              │▓░░▓░▓▓░│  │     (counts on open)
 │  ▲ +37.40 THIS SESSION               └────────┘  │ 96  17px MINT/RED
 │                                       ADD MORE   │ 132 11px MUTED
 │  ┌────────────────────────────────────────────┐  │
 │  │ BOXES 12   HITS 7   BEST +48.00            │  │ 158 15px
 │  │      ▁▂▅▃▇▆█▇█  balance through the run    │  │ 180 sparkline
 │  └────────────────────────────────────────────┘  │
 │                                                  │
 │  CASH OUT SENDS EVERYTHING TO YOUR WALLET  ~4s   │ 248 13px MUTED
 ├──────────────────────────────────────────────────┤
 │ ● < BACK TO PLAY              ◆ CASH OUT >       │
 └──────────────────────────────────────────────────┘
```

- The QR shrinks to a **64px chip in the corner labelled ADD MORE**. It is still
  scannable at 64px for a short EIP-681 URI, still there for a top-up, and no
  longer competing with the thing you came here to do. This single change is
  most of the fix the screen needs.
- The balance is the headline, and it **counts up from the last seen value** when
  the screen opens, so walking in after a good run feels like a good run.
- The session strip gives the run a shape. The sparkline is balance sampled after
  each settle — one list of ints, drawn as a polyline.
- `CASH OUT >` stays in the yellow A slot, where the game's buy button is. Same
  finger, different verb.

**Cap warning.** When the balance is within 10% of `wallet.cap`, the session
strip turns into `NEAR MAX WIN — CASH OUT TO KEEP PLAYING` in YELLOW. Today
that only appears as a fleeting `MAX WIN REACHED / CASH OUT` note mid-game.
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

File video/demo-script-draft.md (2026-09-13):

# ETH Arcade — 3:40 demo film, first cut

Draft pending your answers about the physical device, friends, available timelapses, personal motivation, and whether the integrated testnet flow is running today.

The story: two monitors become one handheld; a friend plays; a session becomes a payout and an ENS record; then the viewer learns they can build the next game.

## Opening choices

**Recommended — visual contrast:** “Two monitors. Twelve charts. Still bored. So we built this.” Use twelve charts only if twelve are actually shown; otherwise say “Too many charts.”

**More personal:** “I wanted to feel the market. Apparently, I needed a knob.” Close-up turn; hard cut into the game.

**Most instantly understandable:** “What if this…” [charts] “…played like this?” [handheld and a friend leaning in].
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

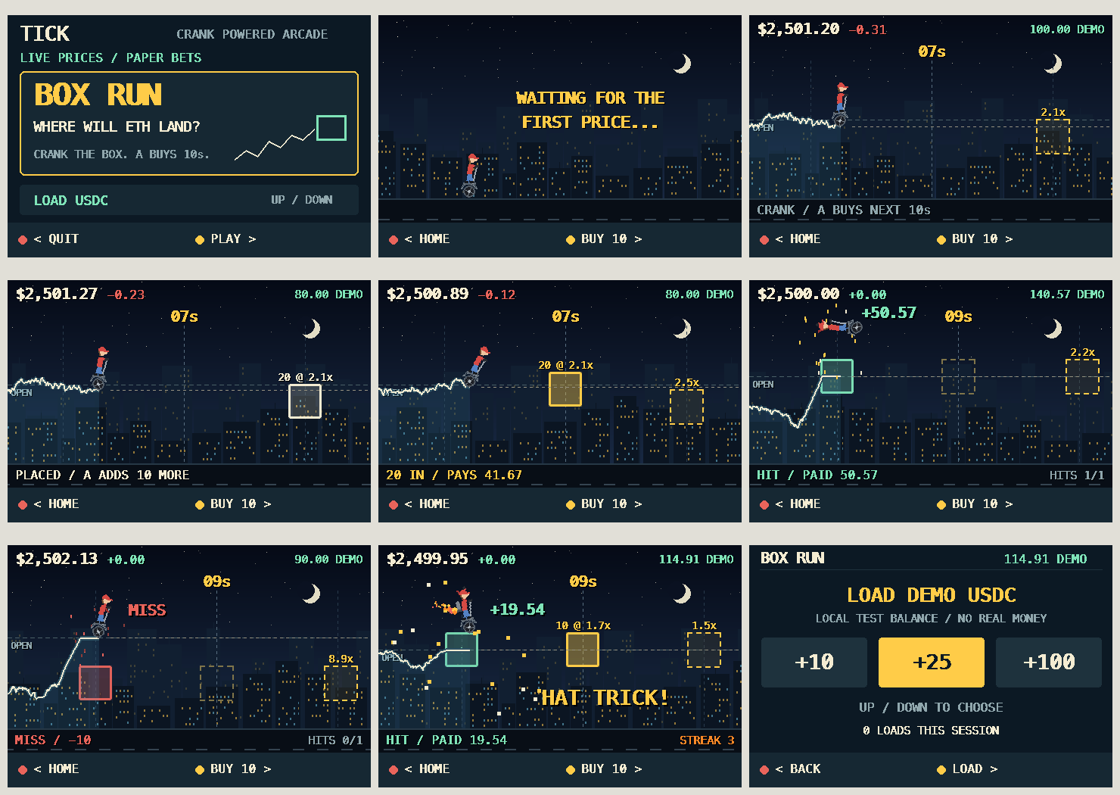
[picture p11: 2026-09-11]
design/box-run-live/gameplay-sheet.png

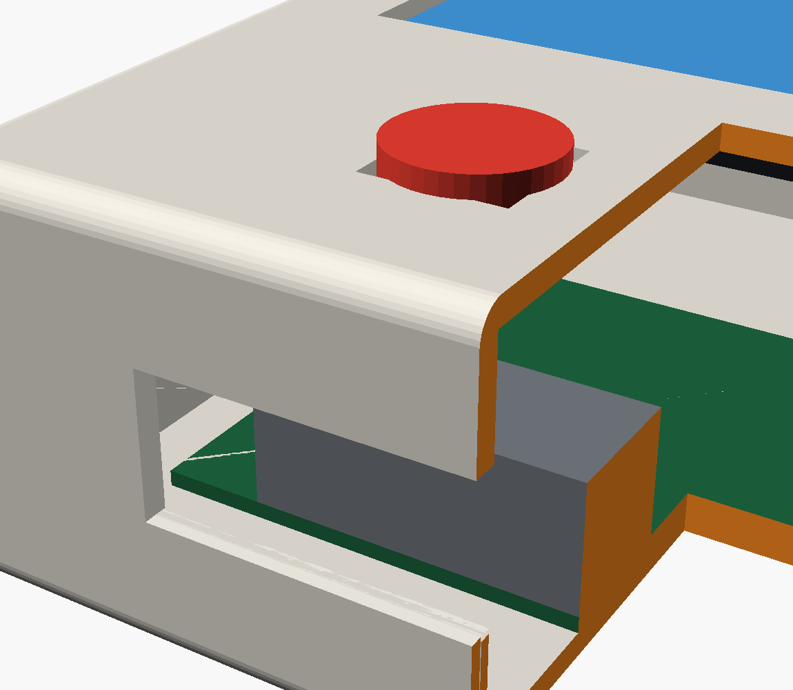
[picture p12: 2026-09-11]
design/cad/section.png

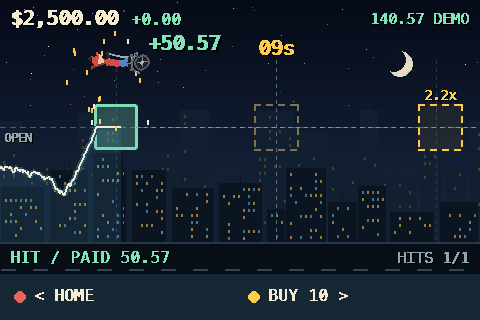
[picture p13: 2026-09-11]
design/box-run-live/hit.png

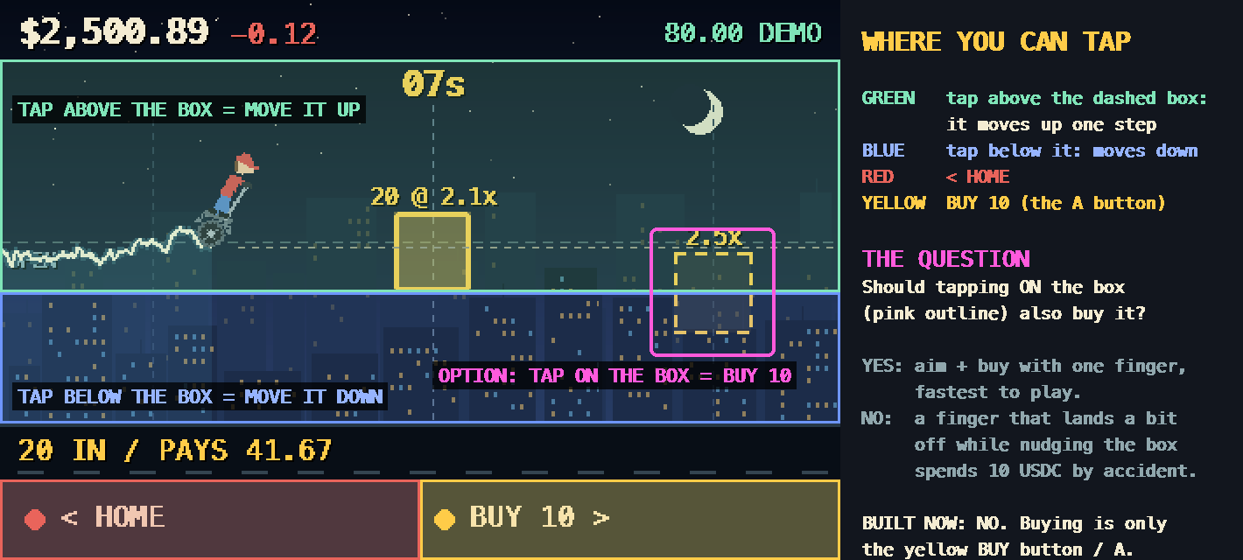
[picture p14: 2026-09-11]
design/box-run-live/touch-zones.png

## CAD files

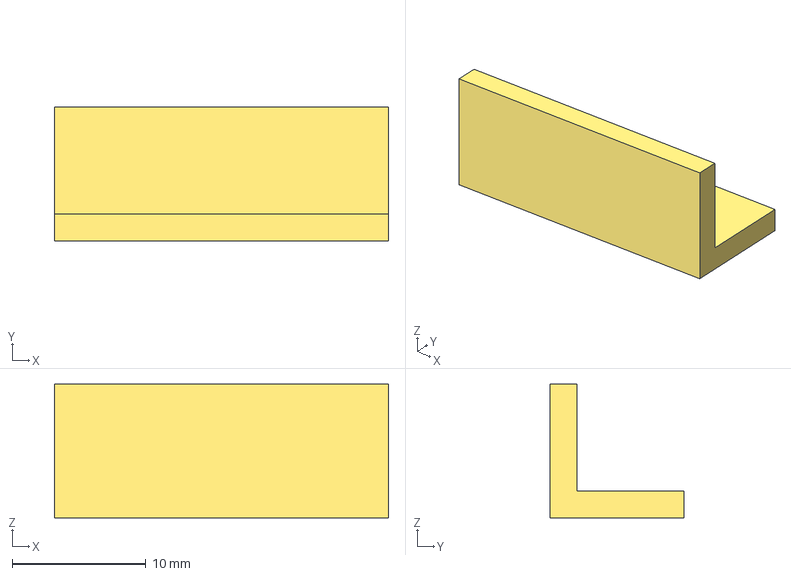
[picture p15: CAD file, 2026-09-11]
design/cad/tick-bracket-l.3mf
25.0 x 10.0 x 10.0 mm

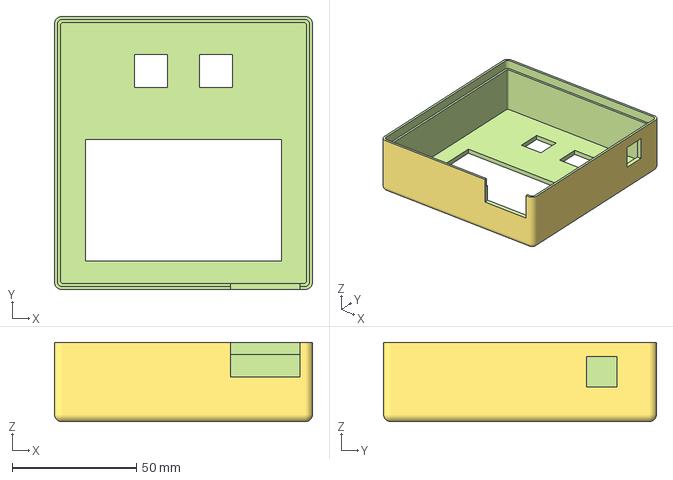
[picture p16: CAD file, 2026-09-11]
design/cad/tick-body.3mf
104.0 x 110.0 x 32.0 mm

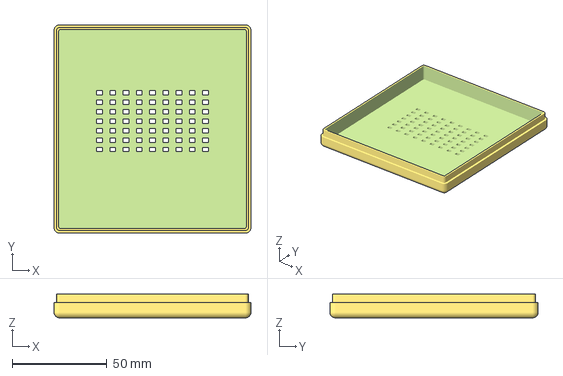
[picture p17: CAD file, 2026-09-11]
design/cad/tick-lid.3mf
104.0 x 110.0 x 12.5 mm

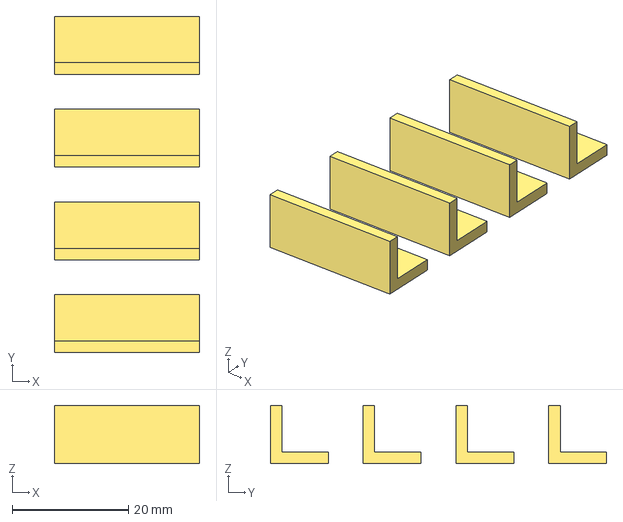
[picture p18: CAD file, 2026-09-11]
design/cad/tick-bracket-l-x4.3mf
25.0 x 58.0 x 10.0 mm

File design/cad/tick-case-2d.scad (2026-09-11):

// TICK handheld - dimensioned 2D review drawing, rev C (all values in mm)
// Six orthographic views. This is the review sheet; the 3D model follows.

// ---- overall -------------------------------------------------------------
W       = 104;   // overall width of the front face
H       = 110;   // overall height of the front face
D       = 40;    // overall depth
WALL    = 2.5;   // shell wall thickness

// ---- screen --------------------------------------------------------------
MOD_W   = 92;    // module including its black bezel
MOD_H   = 60;
VIS_W   = 79;    // visible image, measured off the running panel
VIS_H   = 49;
BEZEL_T = 6;     // face above the module
BEZEL_S = 6;     // face each side of the module
GRIP_H  = H - BEZEL_T - MOD_H;   // 44 of face below the screen

// ---- controls ------------------------------------------------------------
BTN     = 13;    // square button holes
BTN_GAP = 26;    // centre to centre
BTN_CY  = 88;    // button centre, from the top of the face
ENC     = 12;    // square encoder hole, right side face
ENC_CY  = 88;    // encoder centre from the top - on the button line
ENC_CZ  = D/2;   // encoder centre through the depth

// ---- openings ------------------------------------------------------------
// Bottom slot is sized to clear the USB-C AND both micro-HDMI sockets, which
// sit on the same edge of the Pi 5. Wide on purpose: position stops mattering.

// Wide opening in the top face, at its right-hand corner.
TOP_W   = 28;
TOP_D   = 14;
TOP_EDGE = 5;                    // gap left to the right-hand edge
TOP_CX  = W - TOP_EDGE - TOP_W/2;

// ---- back panel ----------------------------------------------------------
SCREW    = 3.2;  // M3 clearance
SCREW_IN = 6;    // screw centres, in from each corner
PI_W = 85; PI_H = 56;            // Raspberry Pi 5 board
PI_HX = 58; PI_HY = 49;          // its mounting hole spacing
PI_EDGE = 3.5;                   // holes in from the board edge
GRILLE_COLS = 9; GRILLE_ROWS = 7; SLOT_W = 3; SLOT_H = 2.2; SLOT_GX = 7; SLOT_GY = 5;

// ---- drawing helpers -----------------------------------------------------
LW = 0.4;
module line(p1, p2, t = LW) {
    d = p2 - p1; a = atan2(d[1], d[0]);
    translate(p1) rotate(a) translate([0, -t/2]) square([norm(d), t]);
}
module frame(w, h, t = LW) {
    difference() { square([w, h]); translate([t, t]) square([w-2*t, h-2*t]); }
}
module ring(r, t = LW) { difference() { circle(r); circle(r - t); } }
module dashed(p1, p2, dash = 2) {
    d = p2 - p1; L = norm(d); n = floor(L / (dash*2));
    for (i = [0:n]) line(p1 + d*(i*2*dash)/L, p1 + d*min(L, (i*2+1)*dash)/L, 0.3);
}
module dbox(w, h) {
    dashed([0,0],[w,0]); dashed([w,0],[w,h]); dashed([w,h],[0,h]); dashed([0,h],[0,0]);
}
module tick(p, vertical = false) {
    translate(p) rotate(vertical ? 90 : 0) translate([-0.2, -1.6]) square([0.4, 3.2]);
}
module dim_h(x1, x2, y, label, size = 3.4) {
    line([x1, y], [x2, y]); tick([x1, y], true); tick([x2, y], true);
    translate([(x1+x2)/2, y + 1.4]) text(label, size = size, halign = "center");
}
module dim_v(y1, y2, x, label, size = 3.4) {
    line([x, y1], [x, y2]); tick([x, y1]); tick([x, y2]);
    translate([x + 1.6, (y1+y2)/2 - size/2]) text(label, size = size);
}
module note(p, txt, size = 3.2) { translate(p) text(txt, size = size); }
module title(p, txt) { translate(p) text(txt, size = 5.5); }

// ---- 1 FRONT -------------------------------------------------------------
module view_front() {
    frame(W, H, 0.6);
    translate([BEZEL_S, GRIP_H]) frame(MOD_W, MOD_H);                       // module
    translate([BEZEL_S + (MOD_W-VIS_W)/2, GRIP_H + (MOD_H-VIS_H)/2])        // window
        frame(VIS_W, VIS_H, 0.6);
    for (dx = [-BTN_GAP/2, BTN_GAP/2])
        translate([W/2 + dx - BTN/2, H - BTN_CY - BTN/2]) frame(BTN, BTN, 0.6);

    dim_h(0, W, -9, str(W, "  overall width"));
    dim_h(BEZEL_S, BEZEL_S + MOD_W, H + 5, str(MOD_W, "  screen module"));
    dim_h(0, BEZEL_S, H + 13, str(BEZEL_S));
    dim_h(W - BEZEL_S, W, H + 13, str(BEZEL_S));
    dim_v(0, H, W + 9, str(H, "  overall height"));
    dim_v(H - BEZEL_T, H, W + 33, str(BEZEL_T, " bezel"));
    dim_v(GRIP_H, GRIP_H + MOD_H, W + 33, str(MOD_H, " screen"));
    dim_v(0, GRIP_H, W + 33, str(GRIP_H, " grip"));
    dim_v(H - BTN_CY, H, -20, str(BTN_CY, " to btn"));
    dim_h(W/2 - BTN_GAP/2, W/2 + BTN_GAP/2, H - BTN_CY - 13, str(BTN_GAP, " ctc"));
    note([W/2 - 27, H - BTN_CY - 25], str(BTN, " x ", BTN, " square buttons"), 3);
    note([BEZEL_S + 3, GRIP_H + MOD_H - 8], str(VIS_W, " x ", VIS_H, " window"), 3);
    title([0, H + 25], "1  FRONT");
}

// ---- 2 BACK --------------------------------------------------------------
module view_back() {
    frame(W, H, 0.6);
    gw = (GRILLE_COLS-1)*SLOT_GX + SLOT_W; gh = (GRILLE_ROWS-1)*SLOT_GY + SLOT_H;
    translate([(W - gw)/2, (H - gh)/2 + 4]) {
        for (c = [0:GRILLE_COLS-1], r = [0:GRILLE_ROWS-1])
            translate([c*SLOT_GX, r*SLOT_GY]) square([SLOT_W, SLOT_H]);
        dim_h(0, gw, -10, str(gw, " x ", gh, " grille"));
    }
    // Pi 5 board and its four mounting holes, seen through the back
    translate([(W - PI_W)/2, 14]) {
        dbox(PI_W, PI_H);
        for (hx = [PI_EDGE, PI_EDGE + PI_HX], hy = [PI_EDGE, PI_EDGE + PI_HY])
            translate([hx, hy]) ring(1.3, 0.4);
    }
    dim_h(0, W, H + 5, str(W));
    dim_v(0, H, W + 9, str(H));
    note([(W-PI_W)/2, 8], str("Pi 5 ", PI_W, " x ", PI_H, " sits loose on the flat lid"), 2.9);
    note([6, H - 12], "lid - presses on, no screws", 2.9);
    title([0, H + 25], "2  BACK  (lid)");
}

// ---- 3 LEFT --------------------------------------------------------------
module view_left() {
    frame(D, H, 0.6);
    dim_h(0, D, -9, str(D, " depth"));
    dim_v(0, H, D + 9, str(H));
    note([D + 15, H/2 - 16], "no openings -", 3);
    note([D + 15, H/2 - 22], "this face is solid", 3);
    title([0, H + 25], "3  LEFT");
}

// ---- 4 RIGHT -------------------------------------------------------------
module view_right() {
    frame(D, H, 0.6);
    translate([ENC_CZ - ENC/2, H - ENC_CY - ENC/2]) frame(ENC, ENC, 0.6);
    dim_h(0, D, -9, str(D, " depth"));
    dim_v(H - ENC_CY, H, D + 9, str(ENC_CY, " to centre"));
    dim_h(ENC_CZ - ENC/2, ENC_CZ + ENC/2, H - ENC_CY + 11, str(ENC));
    dim_h(0, ENC_CZ, -17, str(ENC_CZ, " to centre"));
    note([D + 9, H - ENC_CY - 26], str(ENC, " x ", ENC, " square,"), 3);
    note([D + 9, H - ENC_CY - 32], "rotary encoder shaft", 3);
    title([0, H + 25], "4  RIGHT");
}

// ---- 5 TOP ---------------------------------------------------------------
module view_top() {
    frame(W, D, 0.6);
    translate([TOP_CX - TOP_W/2, (D - TOP_D)/2]) frame(TOP_W, TOP_D, 0.6);
    dim_h(0, W, -9, str(W));
    dim_h(TOP_CX - TOP_W/2, TOP_CX + TOP_W/2, D + 5, str(TOP_W, " wide"));
    dim_h(TOP_CX + TOP_W/2, W, D + 13, str(TOP_EDGE));
    dim_v((D - TOP_D)/2, (D + TOP_D)/2, W + 9, str(TOP_D));
    note([2, D + 22], "wide corner opening - cable exit / venting", 3);
    title([0, D + 30], "5  TOP");
}

// ---- 6 BOTTOM ------------------------------------------------------------
module view_bottom() {
    frame(W, D, 0.6);
    dim_h(0, W, -9, str(W));
    dim_v(0, D, W + 9, str(D, " depth"));
    note([2, D + 22], "solid - no openings. The cable leaves through the TOP.", 3);
    title([0, D + 30], "6  BOTTOM");
}

// ---- sheet ---------------------------------------------------------------
translate([0,   250]) view_front();
translate([200, 250]) view_back();
translate([400, 250]) view_left();
translate([520, 250]) view_right();
translate([0,   140]) view_top();
translate([200, 140]) view_bottom();

translate([0, 410]) title([0, 0], "TICK handheld enclosure - all six faces - rev C");
translate([0, 398]) note([0, 0], str("overall ", W, " W x ", H, " H x ", D, " D   |   wall ", WALL, "   |   all dimensions mm   |   for approval before the 3D model"), 4);

translate([0, 100]) note([0, 0], "DECIDED (was open, now fixed - say so if any of these are wrong)", 4.2);
translate([0, 92]) note([0, 0], "A. Bottom face is solid. The USB-C cable leaves via the top opening, so the Pi must sit with its USB-C edge facing the TOP.", 3.4);
translate([0, 84]) note([0, 0], str("B. Top opening ", TOP_W, " x ", TOP_D, " in the right corner, ", TOP_EDGE, " from the edge - cable exit, and it vents the hot side of the Pi."), 3.4);
translate([0, 76]) note([0, 0], str("C. Encoder centre ", ENC_CY, " down the right face, centred through the depth at ", ENC_CZ, "."), 3.4);
translate([0, 68]) note([0, 0], "D. Left face solid, and both interiors are completely flat - no standoffs, no bosses, nothing to locate parts. Tape or foam at assembly.", 3.4);
translate([0, 60]) note([0, 0], "E. Two parts, no screws: a deep front body and a shallow back lid, pressed together on a 5mm tongue-and-socket lip (0.15 clearance per side).", 3.4);
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

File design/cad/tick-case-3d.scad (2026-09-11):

// TICK handheld enclosure - 3D model (mm). Two printed parts:
//   BODY - the deep front part: screen window, both buttons, the knob
//          opening in the right wall, and the cable opening in the top.
//          The bottom face is solid.
//   LID  - a shallow back dish with the speaker grille
//
// No screws. They press together on a tongue-and-socket lip that runs the
// whole perimeter, so it closes like a box and its lid. The interior of both
// parts is completely flat.
//
// Coordinates: x = 0 left .. 104 right (seen from the front)
//              y = 0 bottom .. 110 top
//              z = 0 back .. 40 front face
//
// VIEW = "assembly" | "exploded" | "body" | "panel" | "four"
VIEW = "assembly";

$fn = 40;

// ---- dimensions (same numbers as the rev C review drawing) ---------------
W = 104; H = 110; D = 40; WALL = 2.5; FILLET = 3;

MOD_W = 92; MOD_H = 60; MOD_T = 3;      // screen module, and its seat depth
VIS_W = 79; VIS_H = 49;                 // visible image = the front window
BEZEL_S = 6; BEZEL_T = 6;
GRIP_H = H - BEZEL_T - MOD_H;           // 44

BTN = 13; BTN_GAP = 26; BTN_CY = 88;    // square buttons, from the top
ENC = 12; ENC_CY = 88; ENC_CZ = D/2;    // encoder square, right wall, on the button line
// The bottom face is solid. The USB-C cable leaves through the top opening,
// which means the Pi must sit with its USB-C edge facing the TOP of the case.

// Cable opening. HOLE_FACE picks which face it lands on.
HOLE_FACE = "top";                      // "top" | "side"
TOP_W = 28; TOP_D = 14; TOP_EDGE = 5;   // smaller than before
TOP_CX = W - TOP_EDGE - TOP_W/2;
TOP_CZ = 15;                            // sits toward the BACK of the top face
SIDE_CY = 20;                           // "side": centre this far down from the top
SIDE_H  = 24;                           // its length along the height

SPLIT = 8;       // where the box splits, measured from the back face
LIP   = 5;       // how deep the two parts overlap
LIP_T = 1.25;    // tongue thickness (half the wall)
PI_W = 85; PI_H = 56; PI_HX = 58; PI_HY = 49; PI_EDGE = 3.5;
CLEAR = 0.3;                            // print clearance added to every hole

// ---- helpers -------------------------------------------------------------
module rounded_box(w, h, d, r) {
    hull() for (x = [r, w-r], y = [r, h-r], z = [r, d-r])
        translate([x, y, z]) sphere(r = r);
}
// A square hole with print clearance, cut along +z from the given face
module hole(w, h) { translate([-CLEAR/2, -CLEAR/2, 0]) cube([w+CLEAR, h+CLEAR, 60]); }

// ---- shared profile ------------------------------------------------------
// 2D footprint inset from the outer wall, used for cavities and the lip
module prof(inset) {
    r = max(0.8, FILLET - inset);
    translate([inset + r, inset + r])
        offset(r = r) square([W - 2*(inset + r), H - 2*(inset + r)]);
}

// ---- BODY: the deep front part -------------------------------------------
module body() {
    difference() {
        rounded_box(W, H, D, FILLET);

        // everything behind the split belongs to the lid
        translate([-10, -10, -60]) cube([W+20, H+20, 60 + SPLIT]);

        // the cavity - a plain flat box, nothing raised in it
        translate([0, 0, SPLIT]) linear_extrude(D - WALL - SPLIT) prof(WALL);
        // socket: the wall thins over the overlap so the lid's tongue sits inside it
        translate([0, 0, SPLIT]) linear_extrude(LIP) prof(WALL - LIP_T);

        // screen window
        translate([BEZEL_S + (MOD_W-VIS_W)/2, GRIP_H + (MOD_H-VIS_H)/2, D-WALL-1])
            cube([VIS_W, VIS_H, WALL+2]);
        // buttons
        for (dx = [-BTN_GAP/2, BTN_GAP/2])
            translate([W/2+dx-BTN/2, H-BTN_CY-BTN/2, D-WALL-1]) hole(BTN, BTN);
        // knob, through the right wall
        translate([W-WALL-1, H-ENC_CY-ENC/2, ENC_CZ-ENC/2])
            rotate([0, 90, 0]) translate([-ENC, 0, 0]) cube([ENC+CLEAR, ENC+CLEAR, WALL+2]);
        // cable opening, on whichever face is selected
        if (HOLE_FACE == "top")
            translate([TOP_CX-TOP_W/2, H-WALL-1, TOP_CZ-TOP_D/2]) cube([TOP_W, WALL+2, TOP_D]);
        else
            translate([W-WALL-1, H-SIDE_CY-SIDE_H/2, D/2-TOP_D/2])
                cube([WALL+2, SIDE_H, TOP_D]);
    }
}

// ---- LID: the shallow back dish ------------------------------------------
module panel() {
    union() {
        difference() {
            intersection() {
                rounded_box(W, H, D, FILLET);
                translate([-10, -10, -1]) cube([W+20, H+20, SPLIT+1]);
            }
            // flat inside
            translate([0, 0, WALL]) linear_extrude(SPLIT) prof(WALL);
            // speaker grille
            for (c = [0:8], r = [0:6])
                translate([(W-59)/2 + c*7, (H-32)/2 + 4 + r*5, -1]) cube([3, 2.2, WALL+2]);
        }
        // tongue that presses into the body's socket
        difference() {
            translate([0, 0, SPLIT]) linear_extrude(LIP - 0.5) prof(WALL - LIP_T + CLEAR/2);
            translate([0, 0, SPLIT-1]) linear_extrude(LIP+2) prof(WALL);
        }
    }
}

// ---- L BRACKET: a loose locator, printed separately ----------------------
// Glue the flat base down wherever the board needs to stop, and the upstand
// catches its edge. Nothing in the case assumes where these go.
LB_LEN  = 25;   // length along the board edge
LB_BASE = 10;   // base flange - the face that gets glued down
LB_UP   = 10;   // upstand the board butts against
LB_T    = 2;    // thickness - thin, as asked

module bracket() {
    cube([LB_LEN, LB_BASE, LB_T]);   // base, flat on the bed
    cube([LB_LEN, LB_T, LB_UP]);     // upstand along one long edge
}

// ---- mock parts, so the pictures show what goes where --------------------
module mock_screen() {
    color("#15181c") translate([BEZEL_S, GRIP_H, D-WALL-MOD_T]) cube([MOD_W, MOD_H, MOD_T]);
    color("#3d8fd0") translate([BEZEL_S+(MOD_W-VIS_W)/2, GRIP_H+(MOD_H-VIS_H)/2, D-WALL-0.2])
        cube([VIS_W, VIS_H, 0.8]);
}
module mock_buttons() {
    cols = ["#d8382c", "#e8b219"];
    for (i = [0, 1]) {
        dx = (i == 0 ? -BTN_GAP/2 : BTN_GAP/2);
        color(cols[i]) translate([W/2+dx, H-BTN_CY, D-WALL-2]) cylinder(r = 7.6, h = 6.5);
    }
}
module mock_encoder() {
    color("#1d3f2a") translate([W-WALL-3, H-ENC_CY-13, ENC_CZ-9.5]) cube([3, 26, 19]);
    color("#9aa3a8") translate([W-WALL, H-ENC_CY, ENC_CZ]) rotate([0, 90, 0]) cylinder(r = 3, h = 14);
}
module mock_pi() {
    color("#1b5e3a") translate([(W-PI_W)/2, 18, WALL]) cube([PI_W, PI_H, 1.6]);
    color("#6b7176") translate([(W-PI_W)/2+10, 18, WALL+1.6]) cube([60, 14, 13]);
}

// ---- views ---------------------------------------------------------------
module assembly() {
    color("#e9e6de") body();
    mock_screen(); mock_buttons(); mock_encoder();
    color("#d9d5cc") panel();
    mock_pi();
}
module exploded() {
    color("#e9e6de") body();
    mock_screen(); mock_buttons(); mock_encoder();
    translate([0, -78, -30]) { color("#d9d5cc") panel(); mock_pi(); }
}

// spin the model rather than the camera: the gimbal makes a true back view awkward
module turned() { translate([W, 0, D]) rotate([0, 180, 0]) assembly(); }

if (VIEW == "assembly") assembly();
else if (VIEW == "back") turned();
// quarter cut through the bottom-left corner, to show the lip engaging
else if (VIEW == "section") difference() {
    assembly();
    translate([W/2, -5, -5]) cube([W, 45, D+10]);
}
else if (VIEW == "exploded") exploded();
else if (VIEW == "body") color("#e9e6de") body();
else if (VIEW == "panel") { color("#d9d5cc") panel(); }
// ---- print orientations, one part per STL --------------------------------
// BODY prints front-face-down: every wall is vertical and the lip socket ends
// up at the top of the print, so no supports are needed.
else if (VIEW == "print_body") translate([0, H, D]) rotate([180, 0, 0]) body();
// LID prints back-face-down; the tongue points straight up.
else if (VIEW == "print_lid") panel();
else if (VIEW == "print_bracket") bracket();
else if (VIEW == "print_brackets") for (i = [0:3]) translate([0, i*(LB_BASE+6), 0]) bracket();
else if (VIEW == "print_both") {
    color("#e9e6de") translate([0, H, D]) rotate([180, 0, 0]) body();
    color("#d9d5cc") translate([W + 16, 0, 0]) panel();
}
else if (VIEW == "four") {
    // front, right, back, left - turned about the vertical axis
    for (i = [0:3]) translate([i*140, 0, 0])
        translate([W/2, 0, D/2]) rotate([0, i*90, 0]) translate([-W/2, 0, -D/2]) assembly();
}

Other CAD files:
design/cad/tick-body.stl
design/cad/tick-bracket-l-x4.stl
design/cad/tick-bracket-l.stl
design/cad/tick-lid.stl

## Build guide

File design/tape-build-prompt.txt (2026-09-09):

Method: built-in image_gen. Appearance concept only. The rendered internal arrangement is not a wiring or assembly reference.

Use case: product-mockup.
Create an honest, practical industrial design concept board for a TWO-DAY hackathon prototype called TICK, a crypto game handheld. It will be FDM 3D PRINTED and assembled with TAPE, with NO SCREWS available. Make it achievable, attractive and deliberately handmade, not an idealized manufactured product.
Board: wide landscape, warm neutral background, three panels: large front-right hero view at left, smaller open-back assembly concept upper right, close-up of taped enclosure seam and simple knob lower right.
Device architecture: a simple deep rectangular burnt-orange printed open tray with modest chamfered corners and visibly layered sidewalls; flat cream printed faceplate resting on its rim; landscape 3.5-inch 3:2 color display behind a plain rectangular window in upper face. Flat surfaces and thick uncomplicated edges, no intricate curves. TWO large simple dark round button caps at lower LEFT, A and B, generous spacing. Lower-right face area is blank except a small TICK wordmark, no extra home button. A SMALL DARK ROUND ROTARY KNOB projects from the right side lower down. NO CRANK ARM, no lever, no spinning crank handle, no metal components on the outside. Knob is a short wide thumbwheel with shallow ridges and is manually rotated. It is visibly a rotary encoder knob, not a joystick.
Assembly: two short strips of matte charcoal cloth tape bridge the front-faceplate-to-orange-sidewall seam, one on each lateral margin, positioned BELOW THE SCREEN and clear of the buttons and knob. Tape looks like real neatly cut removable cloth tape with slightly fibrous edges; it is a considered visible detail. No screws, bolts, screw holes, magnets, snap catches, hinges, or fabricated fasteners anywhere. No tape across display, buttons or ventilation.
Open-back panel: show shell sitting face down with the rear cover lifted away; generic rectangular display rear board at the front, a small Pi-Zero-sized board offset behind it on a simple insulating spacer, loose short wires, bottom cable exit and obvious unused clearance around parts. Electronics are BLOCKING / PACKAGING PLACEHOLDERS, not exact component replicas or certified fit. Flat orange rear lid beside it, ready to tape on. Keep internals visually simple. No batteries. Show external power cable exiting a roomy bottom notch, with slack, not a charging-port claim. Do not suggest tape directly on hot chips.
Screen: attractive but SIMPLE pixel crypto game BOX RUN. Dark navy, chunky cream price line, mint rectangular target, amber "18s", small ETH diamond. No dense tiny dashboard. Matte plastic with believable FDM layers; not glossy injection molded or metallic. Soft studio light, very plausible small hand-sized student prototype.
Only board labels: "TICK / TAPE BUILD", "01 / SIMPLE FRONT", "02 / OPEN TRAY", "03 / TAPE + KNOB". Footer clearly "APPEARANCE CONCEPT / SIZE AND FIT REQUIRE MEASUREMENTS". No dimension arrows or invented measurements. No decorative extra slogans. IMPORTANT: taped assembly, no screws, NO CRANK, no precise fit claim.

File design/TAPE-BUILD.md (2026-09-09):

# TICK — practical tape-assembled prototype

This replaces the screw-fastened enclosure proposal for the two-day build. The accompanying render is an appearance concept; it does not establish component fit or provide printable CAD.

## Simplify the object

- One open printed tray, with flat walls and gently chamfered corners.
- One flat front panel with a rectangular display window and two button holes.
- One flat removable rear cover, attached with short replaceable tape strips.
- A short rotary knob on the right side. Defer the projecting crank until its shaft attachment and support are proven.
- External cable power through an oversized edge notch. No battery packaging or charging work.

Use whatever filament is already available. Cream face / orange tray / dark tape is the visual direction, but a single-color print with neatly trimmed tape also works. All panels are separate pieces; no multi-color printer is required.

## What holds each part

| Part | Practical retention concept | Must check |
|---|---|---|
| Display | Broad internal ledges support the assembly; small retaining pieces or tape attach to suitable non-active frame/PCB margins | No pressure on glass, touch surface, ribbon or exposed components |
| Pi | Insulating support under suitable board edges; accessible connectors | Keep metal contacts isolated, chips uncovered, and tape away from hot components |
| Button switches | A support shelf behind each switch carries pressing force; retain switch body against shelf | Actual switch dimensions and travel; tape alone must not take the repeated press load |
| Encoder | A shaped cradle supports the body with a strap/tape retaining it | Body geometry, wire clearance, shaft length, and resistance to rotation |
| Knob | Short lightweight cap matched to the actual shaft | Shaft profile and fit coupon; no forced fit onto unknown hardware |
| Panels | Panels rest on ledges; short external tape strips keep them seated | Tape must not obstruct screen, controls, cable or ventilation |

Tape retains parts against physical supports; it should not be the only structure resisting button or knob forces. If suitable internal supports cannot be printed in time, use a larger enclosure with accessible foam/card insulating spacers and verify they do not obstruct cooling or damage connectors. Test adhesive on a spare printed patch before choosing strip length.

No screw holes, threaded inserts, magnets, folding hinge or tight sliding lid are required. A lift-off cover avoids spending time tuning sliding tolerances. Use short tape tabs that can be replaced after opening, rather than wrapping the whole device shut.

## Fit before finish

Do not use a fixed outer dimension from an earlier render. Measure or obtain the actual parts first:

1. Display PCB width, height and complete depth, including connectors; active screen position relative to the board.
2. Pi assembly height including its header and attached plugs.
3. Button body dimensions, cap diameter and travel.
4. Encoder body dimensions, shaft diameter/profile, protrusion and wiring.
5. Cable paths with real connectors inserted and relaxed bends.

Lay the parts on paper at full scale. Prefer side-by-side board placement if stacking squeezes cables; allow the shell to become wider/deeper. Print the front window/button layout and encoder cradle as small fit checks before printing a full tray. Add assembly clearance based on those checks rather than promising an arbitrary tolerance.

The board layout inside the render is illustrative. It must not be copied as a verified electronics mounting arrangement.

## Controls and look

Two front buttons, A/B, both at lower left; short right-side knob. Home is reached through B from menus, so there is no third physical button to source. During an active round, B follows the game's explicit state rules rather than silently abandoning a pending operation.

Keep BOX RUN as the first screen: a large ETH price trace, one target box and countdown. Crank-like winding becomes knob rotation with the same software input. The knob is the practical v1 control; a crank can be added later after the mechanism is tested.

Use two neat dark tape tabs on blank face margins below the display as a visible intentional detail. Rear cover tabs can be less decorative. Prioritize a clean screen window, straight tape edges and reliable controls over hidden assembly.

## Two-day assembly check

Before filming: repeat button presses and knob reversals, inspect internal movement, confirm wires are not trapped, run the display/game long enough to check heat and adhesive movement, and reopen the cover once to ensure service access. Check screen readability and touch without pressing on the glass. This is a bench-tested hackathon prototype, not a rugged consumer enclosure.

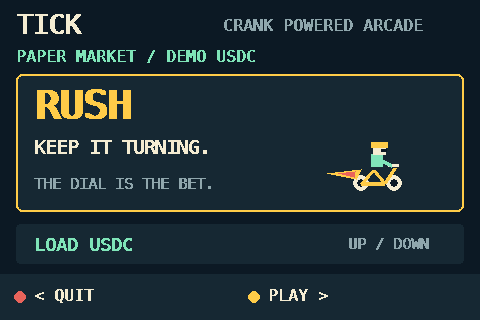
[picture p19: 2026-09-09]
design/rush-build/home.png

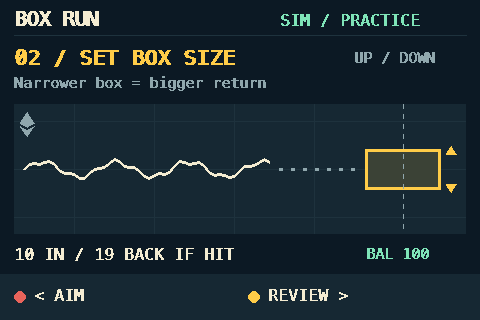
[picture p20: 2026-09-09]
design/box-run-build/size.png

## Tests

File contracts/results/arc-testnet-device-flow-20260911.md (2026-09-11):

# Device flow: Arc testnet, 2026-09-11

The firmware's real-funds path (`TICK_FUNDING=arc-testnet`, `firmware/arc.py`) run end to end against Arc testnet with the real device key, without the screen: the same deposit watcher, `openFor` and `close` the game uses.

- Escrow: [`0x4FA3D366A08aD06D60A0aB141FFb9981EDeE8627`](https://testnet.arcscan.app/address/0x4FA3D366A08aD06D60A0aB141FFb9981EDeE8627)
- Player (and house owner): [`0x7ee85B080701330bf53Be62B7E72fcDD034eCCac`](https://testnet.arcscan.app/address/0x7ee85B080701330bf53Be62B7E72fcDD034eCCac)
- Device: [`0x3E0A93BDaA49710f4052B6e17A4Ac2b3f2f6562E`](https://testnet.arcscan.app/address/0x3E0A93BDaA49710f4052B6e17A4Ac2b3f2f6562E)

| Step | What | Status | Tx |
|---|---|---|---|
| Deposit | Player sends the device 0.05 USDC as a native send (what MetaMask's send screen does) | success | [`0xfff4…79f9`](https://testnet.arcscan.app/tx/0xfff4ea8c3a983b718b0606f54061acb1ec1ca71bfa5926a1a58583d668d779f9) |
| Open | Device sees the transfer, keeps 0.01 for gas, approves the escrow once and calls `openFor`: session 1, 0.04 in the player's name, 0.16 reserved | success, 8.4 s after the deposit | [`0x24f3…c0ec`](https://testnet.arcscan.app/tx/0x24f3990c01acc45b0e23462b346b0c249d090bd77f5c6c47ddb82102d92cc0ec) |
| Close | Device closes at 0.045 (a 0.005 win); the escrow pays the player directly | success | [`0x97c9…bfaf`](https://testnet.arcscan.app/tx/0x97c982d75198b90af0f29a7cc1e05a49e7283e06c28c851d5e8724078f04bfaf) |

## After

| | |
|---|---|
| Player USDC | 29.790958 → 29.785433: −0.05 sent, +0.045 paid back, −0.000525 gas |
| Device USDC | 0.002000 → 0.005018: +0.01 fee, −0.006982 gas for approve, open and close |
| Session 1 open | false |

**PASS**: the session was opened in the sender's name, and the cash-out went straight from the escrow to the address the USDC came from.

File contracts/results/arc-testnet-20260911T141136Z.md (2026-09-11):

# Smoke test: Arc testnet, 2026-09-11 14:11 UTC

One real TickEscrow session against Arc's USDC, run by `smoke.sh`.

- Contract: [`0xbddd8233a65b6f329245dEaFc917543EF48e1daC`](https://testnet.arcscan.app/address/0xbddd8233a65b6f329245dEaFc917543EF48e1daC)
- Player and LP: [`0x7ee85B080701330bf53Be62B7E72fcDD034eCCac`](https://testnet.arcscan.app/address/0x7ee85B080701330bf53Be62B7E72fcDD034eCCac)
- Device: [`0x2A2d05C274D8ea24B6da19048701420bF03c21ba`](https://testnet.arcscan.app/address/0x2A2d05C274D8ea24B6da19048701420bF03c21ba), a fresh key that only signs and never holds USDC

| Step | What | Status | Gas (USDC) | Tx |
|---|---|---|---|---|
| Approve | Player lets the vault pull up to 0.110000 USDC | success | 0.001220 | [`0xb75b…86d7`](https://testnet.arcscan.app/tx/0xb75bd30e4c0902ce34e2679557382201d5673385393db510f45ffd41896a86d7) |
| Open | Session 2: 0.010000 USDC locked, 0.040000 of vault liquidity reserved | success | 0.004003 | [`0x3b9f…3b35`](https://testnet.arcscan.app/tx/0x3b9ff4eba5b0a0080cbd5f64abce28397cee68a8d30b7ce255b7ad33a0393b35) |
| Close | Device signs a final balance of 0.015000; the player submits it | success | 0.001513 | [`0x6f67…009d`](https://testnet.arcscan.app/tx/0x6f67005bce023b7a730cbae88f45e505d82330c81bffe8fd61d05dffb734009d) |

## After

| | |
|---|---|
| Player USDC | 39.788544 → 39.786809 |
| Win paid from the vault | 0.005000 USDC |
| Session 2 open | false |
| Vault assets | 0.090000 USDC |
| Vault reserved / player funds | 0.000000 / 0.000000 USDC |
| Total gas | 0.006735 USDC |

**PASS**: session 2 is closed and the player's balance moved by exactly the seed, deposit, payout and gas.

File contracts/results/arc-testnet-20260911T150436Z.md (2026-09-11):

# Smoke test: Arc testnet, 2026-09-11 15:04 UTC

One real TickEscrow session against Arc's USDC, run by `smoke.sh`.

- Contract: [`0xC50dC94A6b9AB85A5B541Da9DB5df83870A41b3B`](https://testnet.arcscan.app/address/0xC50dC94A6b9AB85A5B541Da9DB5df83870A41b3B)
- Player and house owner: [`0x7ee85B080701330bf53Be62B7E72fcDD034eCCac`](https://testnet.arcscan.app/address/0x7ee85B080701330bf53Be62B7E72fcDD034eCCac)
- Device: [`0x1EBaba2e05D833C654c0cb8595A2F09D18445DA8`](https://testnet.arcscan.app/address/0x1EBaba2e05D833C654c0cb8595A2F09D18445DA8), a fresh key that only signs and never holds USDC

| Step | What | Status | Gas (USDC) | Tx |
|---|---|---|---|---|
| Approve | Player lets the contract pull up to 0.110000 USDC | success | 0.001220 | [`0x70fa…0555`](https://testnet.arcscan.app/tx/0x70fa1cfc1105c177ba9d11c7ac6aac44bb02c44fa914d8f6249e9116129a0555) |
| Fund | Owner funds the house with 0.100000 USDC | success | 0.001295 | [`0xaa78…402e`](https://testnet.arcscan.app/tx/0xaa78326e715ecb60a44fef795f1883205d9d2c73d50ea2eaeb25ba4509c0402e) |
| Open | Session 1: 0.010000 USDC locked, 0.040000 of house money reserved | success | 0.004483 | [`0xc41a…f850`](https://testnet.arcscan.app/tx/0xc41a184aeef8216d882a8e705bc0789eb5e0aef1efde77d8db255677434df850) |
| Close | Device signs a final balance of 0.015000; the player submits it | success | 0.001503 | [`0x0ec3…13bd`](https://testnet.arcscan.app/tx/0x0ec3721c841ac54381864ea9d2b64c41c6001a38c9754a2cec6025fb802213bd) |

## After

| | |
|---|---|
| Player USDC | 39.753329 → 39.649828 |
| Win paid from the house | 0.005000 USDC |
| Session 1 open | false |
| House withdraw while the session was open | SessionsOpen |
| House withdraw after it closed | ok |
| House balance | 0.095000 USDC |
| Reserved / player funds | 0.000000 / 0.000000 USDC |
| Total gas | 0.008501 USDC |

**PASS**: session 1 is closed, the player's balance moved by exactly the seed, deposit, payout and gas, and the house could withdraw only once the session closed.

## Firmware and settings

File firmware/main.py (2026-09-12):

"""Entry point for the ETH Arcade handheld launcher and BOX RUN."""

from display_setup import ensure_system_pygame
from envfile import load_env_file

# Before the display bootstrap, which may re-exec with this environment.
load_env_file()
ensure_system_pygame()

import keeper  # noqa: E402
from app import App  # noqa: E402


def main() -> None:
    keeper.start()    # names and scores the players; the game runs with or without it
    App().run()


if __name__ == "__main__":
    main()

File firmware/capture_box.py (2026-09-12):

"""Capture the actual BOX RUN UI from the real game on a scripted clock.

No image generation. The clock is injected so the sequence is reproducible, and
the price is steered — the real sim feed plus a slowly ramped offset — so a hit,
a miss and a hat trick can each be photographed. Everything drawn is the real
renderer reading the real model.
"""
from dataclasses import replace
from pathlib import Path

import pygame

from games.box import BoxGame, BOX_W, STREET_BOTTOM
from screens.home import HomeScreen
from ui import CREAM, MINT, MUTED, YELLOW, RED, font
from wallet import MICRO, DemoFunding, Wallet

FRAME = 1/30
STATES = ['home', 'waiting', 'aiming', 'bought', 'live', 'hit', 'miss', 'hattrick', 'wallet']


class Clock:
    def __init__(self, start: float = 5000.0) -> None:
        self.t = start

    def __call__(self) -> float:
        return self.t


class Steered:
    """The sim feed, plus an offset that ramps to wherever the shot needs it.

    The offset is kept once reached, so the price never snaps back: the trace
    looks like a market that happened to walk there.
    """

    def __init__(self, inner) -> None:
        self.inner, self.name = inner, inner.name
        self.offset = 0.0
        self.plan: tuple[float, float, float, float] | None = None  # from, to, start, ramp
        self.last = 0.0

    def aim_for(self, price: float, start: float, ramp: float = 2.0) -> None:
        self.plan = (self.offset, price, start, ramp)

    def poll(self, dt, now):
        out = []
        for tick in self.inner.poll(dt, now):
            if self.plan is not None:
                was, goal, start, ramp = self.plan
                if now >= start:
                    blend = min(1.0, (now - start) / ramp)
                    self.offset = was + (goal - tick.price - was) * blend
            out.append(replace(tick, price=tick.price + self.offset))
        return out

    def close(self) -> None:
        self.inner.close()


def new_game(clock: Clock, seed: int = 11) -> BoxGame:
    game = BoxGame(seed=seed, sound=False, source='sim',
                   wallet=Wallet(100 * MICRO, DemoFunding()), clock=clock)
    game.feed = Steered(game.feed)
    # Presses here are scripted, never a finger carried past the bell, so the
    # fresh cursor's arming delay would only push every shot out of frame.
    game.ARM_S = 0.0
    return game


def run(game: BoxGame, clock: Clock, seconds: float) -> None:
    for _ in range(int(seconds / FRAME)):
        clock.t += FRAME
        game.update(FRAME)


def ride_to_bell(game: BoxGame, clock: Clock, price: float, after: float) -> None:
    """Walk the price to `price` over the last seconds, then run past the bell."""
    m = game.model
    game.feed.aim_for(price, m.window_end - 3.2)
    run(game, clock, m.remaining(clock.t) + after)


def to_live(game: BoxGame, clock: Clock) -> None:
    """Buy the next window, then wait out the bell so the box is the live one."""
    game.buy()
    run(game, clock, game.model.remaining(clock.t) + .5)


def touch_sheet(frame: pygame.Surface, game: BoxGame) -> pygame.Surface:
    """The live frame at 2x, with every place you can tap drawn over it."""
    m = game.model
    scale = 2
    art = pygame.transform.scale(frame, (frame.get_width() * scale, frame.get_height() * scale))
    aim = game.box_rect(game.x_at(m.window_end + m.WINDOW_S),
                        game.aim_price - m.half, game.aim_price + m.half)
    play_top, play_bottom = 34, STREET_BOTTOM - 32

    def zone(rect, color, alpha=70):
        glass = pygame.Surface((rect[2] * scale, rect[3] * scale), pygame.SRCALPHA)
        glass.fill((*color, alpha))
        art.blit(glass, (rect[0] * scale, rect[1] * scale))
        pygame.draw.rect(art, color, [v * scale for v in rect], 3)

    zone((0, play_top, 480, aim.centery - play_top), MINT, 45)
    zone((0, aim.centery, 480, play_bottom - aim.centery), (110, 150, 255), 45)
    zone((0, STREET_BOTTOM, 240, 320 - STREET_BOTTOM), RED)
    zone((240, STREET_BOTTOM, 240, 320 - STREET_BOTTOM), YELLOW)
    pad = aim.inflate(28, 28)
    pygame.draw.rect(art, (255, 90, 220), [v * scale for v in pad], 4, border_radius=8)

    def tag(text, x, y, color):
        t = font(22).render(text, False, color)
        back = pygame.Surface((t.get_width() + 12, t.get_height() + 6), pygame.SRCALPHA)
        back.fill((0, 0, 0, 190))
        art.blit(back, (x - 6, y - 3))
        art.blit(t, (x, y))

    tag('TAP ABOVE THE BOX = MOVE IT UP', 20, (play_top + 22) * scale, MINT)
    tag('TAP BELOW THE BOX = MOVE IT DOWN', 20, (play_bottom - 22) * scale, (150, 180, 255))
    tag('OPTION: TAP ON THE BOX = BUY 10', 500, (pad.bottom + 4) * scale, (255, 90, 220))

    sheet = pygame.Surface((art.get_width() + 460, art.get_height()))
    sheet.fill((18, 22, 30))
    sheet.blit(art, (0, 0))
    notes = [
        ('WHERE YOU CAN TAP', YELLOW, 30),
        ('', CREAM, 20),
        ('GREEN   tap above the dashed box:', MINT, 20),
        ('        it moves up one step', CREAM, 20),
        ('BLUE    tap below it: moves down', (150, 180, 255), 20),
        ('RED     < HOME', RED, 20),
        ('YELLOW  BUY 10 (the A button)', YELLOW, 20),
        ('', CREAM, 20),
        ('THE QUESTION', (255, 90, 220), 26),
        ('Should tapping ON the box', CREAM, 20),
        ('(pink outline) also buy it?', CREAM, 20),
        ('', CREAM, 20),
        ('YES: aim + buy with one finger,', MUTED, 20),
        ('     fastest to play.', MUTED, 20),
        ('NO:  a finger that lands a bit', MUTED, 20),
        ('     off while nudging the box', MUTED, 20),
        ('     spends 10 USDC by accident.', MUTED, 20),
        ('', CREAM, 20),
        ('BUILT NOW: NO. Buying is only', CREAM, 20),
        ('the yellow BUY button / A.', CREAM, 20),
    ]
    y = 30
    for text, color, size in notes:
        sheet.blit(font(size).render(text, False, color), (art.get_width() + 24, y))
        y += size + 10
    return sheet
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

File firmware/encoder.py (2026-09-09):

"""Rotary encoder on GPIO → InputAction (turn = UP/DOWN, click = A, hold = B).

Wiring (BCM): CLK=21, DT=20, SW=16, VCC=3.3V, GND=GND.
Uses system gpiozero/lgpio (available after display_setup re-exec on Pi).
"""

from __future__ import annotations

import time
from typing import Callable

from input import InputAction

# BCM pin map for this handheld
CLK_PIN = 21
DT_PIN = 20
SW_PIN = 16

LONG_PRESS_S = 0.65
# Ignore sub-detent chatter; KY-040 often reports 1–2 gpiozero steps per click.
STEPS_PER_CLICK = 1
# Don't emit more than one nav action this often (fast spin = steady scroll).
MIN_NAV_INTERVAL_S = 0.05


class EncoderInput:
    """Poll-based encoder reader. Safe to call each frame from the pygame loop."""

    def __init__(
        self,
        encoder: object,
        button: object,
        *,
        invert: bool = False,
    ) -> None:
        self._encoder = encoder
        self._button = button
        self._invert = invert
        self._last_steps = int(getattr(encoder, "steps", 0))
        self._pending = 0  # accumulated signed steps toward next click
        self._was_pressed = bool(getattr(button, "is_pressed", False))
        self._press_at = 0.0
        self._last_nav_at = 0.0

    @classmethod
    def try_open(
        cls,
        clk: int = CLK_PIN,
        dt: int = DT_PIN,
        sw: int = SW_PIN,
        invert: bool = False,
    ) -> EncoderInput | None:
        try:
            from gpiozero import Button, Device, RotaryEncoder
            from gpiozero.pins.lgpio import LGPIOFactory
        except ImportError:
            return None

        try:
            if Device.pin_factory is None:
                Device.pin_factory = LGPIOFactory(chip=0)
            # max_steps=0 → unlimited. The default of 16 clamps and "breaks"
            # after a fast spin in one direction.
            # No bounce_time: mechanical filtering drops edges when spun fast.
            encoder = RotaryEncoder(clk, dt, bounce_time=None, max_steps=0)
            button = Button(sw, pull_up=True, bounce_time=0.05)
        except Exception:
            return None

        return cls(encoder, button, invert=invert)

    def poll(self, *, continuous: bool = False) -> list[InputAction]:
        actions: list[InputAction] = []
        now = time.monotonic()

        steps = int(self._encoder.steps)
        delta = steps - self._last_steps
        self._last_steps = steps
        if continuous:
            # Gameplay uses only this poll's motion. Never queue old turns:
            # a stopped crank must stop pumping immediately.
            self._pending = 0
            if self._invert:
                delta = -delta
            action = InputAction.UP if delta > 0 else InputAction.DOWN
            actions.extend([action] * min(16, abs(delta)))
        elif delta:
            if self._invert:
                delta = -delta
            self._pending += delta

            # Emit at most one nav action per interval so a whip-spin scrolls
            # smoothly instead of wrapping the list dozens of times.
            while abs(self._pending) >= STEPS_PER_CLICK:
                if now - self._last_nav_at < MIN_NAV_INTERVAL_S:
                    # Keep residual steps (don't discard) but wait to fire.
                    break
                if self._pending > 0:
                    actions.append(InputAction.DOWN)
                    self._pending -= STEPS_PER_CLICK
                else:
                    actions.append(InputAction.UP)
                    self._pending += STEPS_PER_CLICK
                self._last_nav_at = now
                now = time.monotonic()
                # One action per poll keeps the UI in sync with a single frame.
                break

            # Direction reverse: drop leftover chatter from the other way.
            if actions and (
                (actions[-1] == InputAction.DOWN and self._pending < 0)
                or (actions[-1] == InputAction.UP and self._pending > 0)
            ):
                self._pending = 0

        pressed = bool(self._button.is_pressed)
        if pressed and not self._was_pressed:
            self._press_at = now
        elif not pressed and self._was_pressed:
            held = now - self._press_at
            actions.append(InputAction.B if held >= LONG_PRESS_S else InputAction.A)
        self._was_pressed = pressed

        return actions

    def close(self) -> None:
        close: Callable[[], None] | None
        for device in (self._encoder, self._button):
            close = getattr(device, "close", None)
            if close is not None:
                try:
                    close()
                except Exception:
                    pass

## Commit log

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2026-09-09 Add design documentation for TICK handheld arcade, including device concept, product direction, and screen studies. Introduced game mechanics and visual direction for initial prototypes. Added image 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
2026-09-09 Add RUSH: continuous-crank leveraged market ride with demo USDC
    RUSH replaces the box-sizing flow with a single continuous action: crank
    the encoder to hold throttle, which maps to 1x-10x leverage on a live
    paper position. Releasing the crank exits the ride.
    - markets/feed.py: switchable simulated and read-only Coinbase adapters
    behind TICK_MARKET_SOURCE; ticks carry sequence and source age so
    stale quotes never reprice exposure.
    - games/rush_model.py: dummy USDC wallet with explicit loads, throttle
    decay, and settlement that marks the previous quantity before changing
    exposure.
    - encoder.py: continuous poll mode so gameplay reads only current motion
    and a stopped crank stops pump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
    [app.py, encoder.py]
2026-09-09 Drop box sizing; make the crank itself the whole bet
    Feedback: no aim/size/confirm steps, live prices, loadable money and
    leverage, with one continuous crank instead of stepping through screens.
    - Turning the dial IS the bet: two detents open a position in the
    direction turned, then every detent pumps a flywheel whose level is
    the 1x-10x leverage. Stop turning and it bleeds down; let it die and
    the ride closes. Results land in place, so cranking through one opens
    the next. No confirmation path exists in the model at all.
    - wallet.py: balances as integer micro-USDC (real USDC's 6 decimals) so
    a session cannot drift, settlement truncates dust downward, and
    funding sits behind a ba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
    [app.py, capture_rush.py, theme.py]
2026-09-09 Bring back BOX RUN: live prices, 20s windows, one crank
    The box was the game; only its sizing step was in the way. This restores
    the box on a live price ladder with the aim/size/confirm flow gone.
    - games/box_model.py: a 20-second window clock that never stops. The dial
    moves an aim cursor; A buys the next window at the cursor for 10 USDC,
    and further presses add stake to that same box. Once bought the level
    is fixed and the box rides to the bell.
    - Distance from spot is the only risk dial, priced from measured
    volatility of the live tick stream over the true remaining horizon, so
    buying early prices the drift it actually carries. Each press is
    priced at its own odds: topping up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
    [app.py, capture_box.py, input.py]
2026-09-09 Constant box size, a visible lock, and a chart you can read moves on
    Three pieces of feedback from playing it, and the third explains the
    second.
    The box was sized in sigma of measured volatility, so it changed size on
    screen — worst of all under a bet already placed, which kept its
    purchase-time height while the view rescaled around it. Geometry is now
    fixed in basis points of the window's opening price: a $2.00 box, 25c
    steps and $3.00 of reach on $2,500 ETH. Volatility moves the odds and
    never the box. A violent market makes the same box harder to hit and the
    multiple rises to match, which is the honest response rather than
    quietly enlarging the target.
    That freed the view to zoom in,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
    [capture_box.py]
2026-09-10 Give the game a voice: crossing swoops and a rushing countdown
    The sound was six fixed beeps. It is now a small synth (square waves
    with a carried phase, so a clip can glide rather than only beep) driving
    cues that answer what the screen otherwise makes you read.
    The two that carry the tension: an upward swoop when the price crosses
    INTO your live box and a downward one when it leaves, and countdown
    ticks pitched high when the money is currently winning, low when it is
    not — doubling in rate inside the final two seconds so the bell rushes
    at you. Together they mean you can tell whether you are winning without
    looking at the panel.
    Also: crank detents rise in pitch as the box moves out to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
    [ui.py]
2026-09-10 Add reactive chiptune music and a fuller cue set
    The game had cues but no score, so it sat silent between events. It now
    has three looping beds and picks one every frame from what is at stake:
    sparse A-minor bass when nothing is down, driving bass with a fast
    arpeggio and hats once money is on a window, and a tense descending lead
    with hats on every step for the last three seconds. The launcher hums on
    the idle bed too.
    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
2026-09-10 feat: add tick_eth_price module for Uniswap v3 pool price tracking
    - Introduced new protobuf definitions for handling block prices and events related to Uniswap v3.
    - Implemented a streaming script to fetch and merge price data from multiple chains.
    - Created a new YAML configuration for the tick_eth_price module, specifying dependencies and parameters.
    - Added generated Rust files for handling protobuf messages related to block prices and events.
2026-09-11 feat: support Uniswap v4 pools in price tracking module
    - Updated the price tracking module to handle both Uniswap v3 and v4 pools.
    - Enhanced the parsing logic to accommodate v4 pool IDs.
    - Introduced a new protobuf definition for Uniswap v4 events.
    - Modified the stream.sh script to ensure proper termination of child processes.
    - Updated the substreams.yaml configuration to include Uniswap v4 package.
    - Added unit tests for the new functionality, ensuring accurate price calculations.
    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
2026-09-11 Add box_scene.py: Implement night city scenery with a one-wheel rider
    This commit introduces a new module, box_scene.py, which creates a dynamic night city environment featuring a one-wheeled rider. The scenery is rendered entirely through code, utilizing Pygame for gr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
2026-09-11 feat: Add MockUSDC contract for testing and implement Arc funding mechanism
    - Introduced MockUSDC contract to simulate USDC behavior in tests.
    - Developed Arc funding logic to handle real USDC transactions on the Arc testnet.
    - Implemented a comprehensive test suite for Arc funding, including session management and cash-out functionality.
    - Added stake settings and display tests to ensure correct handling of stake amounts in the game models.
    [arc.py]
2026-09-11 Add the red and yellow panel buttons on GPIO13 and GPIO26
    Each button shorts its pin to ground against the internal pull-up, so
    no external parts are needed. The mapping matches the footer the games
    already draw: red on the left is back, yellow on the right is go.
    Presses are edge-triggered off a per-frame poll, like the encoder's own
    switch, so holding a button repeats nothing and a button already held
    when the game starts is read as the resting state rather than firing on
    the first frame. If a pin is missing or already claimed by an overlay
    the pad quietly does not open and the encoder carries on alone, so a
    desktop or an unwired device loses nothing.
    BCM numbering: GPIO13 is header pin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
    [app.py, buttons.py]
2026-09-11 Add dimensioned 2D review drawing for the handheld case
    Four orthographic views (front, right side, top, back) built from the
    sketch and the measurements taken off the running device. Parametric, so
    approving a change is a one-line edit and a re-render.
    Agreed with the sketch: 104 W x 110 H x 40 D, screen module 92 x 60
    inset 6 from the top with 6 bezels each side, 44mm grip below carrying
    two 13mm square buttons at 26 centre-to-centre, 12mm square encoder hole
    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
    [tick-case-2d.scad]
2026-09-11 Review drawing rev B: USB-C to the bottom, wide top-right opening
    Per feedback the openings are now on three faces - TOP (a wide corner
    opening on the right), RIGHT (the 12mm encoder square) and BOTTOM
    (USB-C).
    The USB-C slot is 40 x 12, far larger than the connector itself, so the
    Pi's exact position inside stops mattering. The top-right opening is a
    34 x 16 placeholder until I know what passes through it.
    [tick-case-2d.scad]
2026-09-11 Review drawing rev C: all six faces dimensioned
    Adds the left face and the back panel detail (4x M3 at 92 x 98 centres,
    Pi 5 outline with its M2.5 standoff pattern at 58 x 49), so every face
    is now dimensioned and nothing about the shell is left to inference.
    Closed the remaining open items rather than asking again:
    - Bottom slot widened to 60 x 14. The Pi 5 carries USB-C and both
    micro-HDMI on a single edge spanning ~60mm, so a connector-sized hole
    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
    [tick-case-2d.scad]
2026-09-11 Add the 3D case model with rendered views
    The dimension sheet was not readable without CAD experience, so this
    adds the actual model and pictures of it.
    Two printed parts, same numbers as the rev C drawing: BODY is the front
    shell carrying the screen window, module seat, both button squares, the
    encoder square in the right wall, the wide top-right opening and the
    bottom USB-C slot, with four corner bosses; PANEL is the back plate with
    the speaker grille, four screw holes and the standoffs the Pi bolts to.
    Mock screen, buttons, encoder and Pi are included in the render views so
    the pictures show what goes where. Every hole carries 0.3mm of print
    clearance.
    Renders: front, back and exploded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
    [tick-case-3d.scad]
2026-09-11 Knob to the bottom right; flat interior
    Two corrections.
    The encoder was at ENC_CY 46, which is 46mm down from the top and so
    sits above the middle of the right face. It is now 88, the same as the
    button centres, putting the knob in the grip area at the bottom right
    where the thumb already is. The 2D sheet follows the same constant.
    The interior had two things standing proud that should not have been
    there: four standoffs on the back panel lifting the Pi, and a recessed
    seat in the front wall for the screen module. Both are gone. The back
    panel is a flat plate and the inner face of the front wall is flat, so
    the cavity is a plain box.
    Still proud inside: the four corner screw bosses that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
    [tick-case-2d.scad, tick-case-3d.scad]
2026-09-11 No screws: the case now closes like a box and its lid
    Replaces the screwed back panel and its four corner bosses with a
    press fit. A tongue-and-socket lip runs the whole perimeter: the body's
    wall thins to 1.25 over the last 5mm to form a socket, and the lid
    carries a 1.1 thick tongue that presses into it, 0.15 clearance a side.
    The split sits 8mm from the back, which keeps every opening - screen,
    both buttons, the knob in the right wall, the top corner opening and the
    bottom USB slot - in the deep front part. The lid is a plain shallow
    dish carrying only the speaker grille.
    Both interiors are now completely flat. Nothing locates the Pi or the
    screen, so they want tape or foam at assembly,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
    [tick-case-2d.scad, tick-case-3d.scad]
2026-09-11 Export printable STLs; solid bottom, taller L brackets
    Three printed parts, all watertight, all sitting flat at z=0 so they
    drop onto the bed with no rotation:
    tick-body.stl 104 x 110 x 32 - prints front-face-down, so the
    face you look at is the one on the glass and every
    wall is vertical
    tick-lid.stl 104 x 110 x 12.5 - prints back-down, tongue up
    tick-bracket-l.stl 25 x 10 x 10 - loose L locator
    tick-bracket-l-x4.stl 25 x 58 x 10 - four on one plate
    Removed the bottom USB slot. It was redundant once the cable exits
    through the top opening, and deleting it took out a 60mm bridge and left
    the bottom wall unbroken.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
    [tick-body.stl, tick-bracket-l-x4.stl, tick-bracket-l.stl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]
2026-09-11 Add 3MF alongside the STLs
    Same four parts exported through lib3mf. 3MF carries the unit
    explicitly - each file declares millimetre - so there is no chance of a
    slicer guessing inches, which is the usual way an STL import goes wrong.
    The files are also roughly a quarter the size.
    Verified by opening each archive and reading the model XML: one object
    per file, geometry and bounds matching the STLs exactly, and every part
    still starting at z=0.
    [tick-body.3mf, tick-bracket-l-x4.3mf, tick-bracket-l.3mf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]
2026-09-11 Add scorekeeper tests, leaderboard functionality, and pool management script
    - Implement unit tests for the scorekeeper in `ens/test_scorekeeper.py` to validate player session handling and USDC calculations.
    - Create `firmware/names.py` to manage player names and ENS interactions, including name registration and stats retrieval.
    - Develop `firmware/screens/board.py` for displaying a leaderboard of players, integrating real-time data from ENS.
    - Add tests for the leaderboard functionality in `firmware/tests/test_board.py` to ensure correct player ranking and display logic.
    - Introduce `firmware/tests/test_names.py` to validate ENS name handling and statistics retrieval.
    - Create `substreams/p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
    [app.py, arc.py, names.py]
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2026-09-11 Remove deprecated `shot.html` file and refactor scroll handling in `scroll.ts`. Update button structure in `Demo.tsx` to include icon elements, enhance CSS styles for button and dial components, and 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
2026-09-12 Add Proof section and enhance App layout
    - Introduced a new `Proof` component detailing the underlying technology and architecture of the device.
    - Updated `App.tsx` to include the `Proof` section in the main layout.
    - Enhanced `Chrome.tsx` navigation with a link to the new `Proof` section.
    - Revised `Demo.tsx` to improve state management and display of settled windows.
    - Updated `Reserve.tsx` to clarify reservation process and pricing information.
    - Adjusted CSS styles for better visual consistency and responsiveness across components.
2026-09-12 Update device specifications and styling
    - Revised the device description in `index.html` to include specific components: Raspberry Pi Zero W and a 3.5-inch screen.
    - Updated `Film.tsx` and `Reserve.tsx` to reflect the use of Raspberry Pi Zero W in the device's specifications.
    - Adjusted CSS styles for the dial component to enhance visual appeal with new gradient colors.
    - Modified `Device.tsx` and `pcb.ts` to accurately represent the Raspberry Pi Zero W's dimensions and features.
    - Improved camera rig positioning in `rig.ts` for better visual representation.
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2026-09-12 Fix cursor arming delay in BoxGame to prevent unintended box locking and enhance gameplay experience. Update tests to validate new behavior.
    [capture_box.py]
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2026-09-12 Update insert coin design and functionality in mockup script
    - Replaced the coin slot function with a new pulse animation for visual feedback.
    - Enhanced the waiting rider's appearance and behavior to better indicate readiness for coin insertion.
    - Updated README.md to reflect changes in the design, emphasizing the waiting sign's role and the blinking dots.
    - Modified QR code placement for improved aesthetics and functionality.
2026-09-12 Update design and functionality for money screen in ETH Arcade
    - Replaced references from "CASHIER" to "MONEY" across various files to align with new branding.
    - Updated mockup generation script to reflect changes in screen titles and visuals.
    - Enhanced the `make_mockups.py` script to include updated screen designs and improved layout for the money screen.
    - Revised documentation in `SPEC.md` and `README.md` to clarify the new money screen functionality and user interactions.
    - Added new functionality in `app.py` to handle transitions to the money screen and manage user actions related to real funds.
    [app.py, main.py]
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

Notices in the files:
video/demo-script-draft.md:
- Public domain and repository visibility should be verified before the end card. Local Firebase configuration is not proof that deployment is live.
